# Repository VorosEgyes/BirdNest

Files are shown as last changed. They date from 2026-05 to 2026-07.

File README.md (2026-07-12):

# BirdNest ESP32-CAM Project

BirdNest is a battery-aware ESP32-CAM wildlife and bird nest monitoring project built with PlatformIO and Arduino. It captures photos on schedule or command, sends images and status updates to Telegram, and supports MQTT telemetry for smart home and IoT integrations. The firmware includes deep sleep power saving, OTA remote updates, WiFi recovery logic, DS18B20 temperature monitoring, and calibrated battery voltage reporting for reliable long-term outdoor operation.

**Single firmware binary model.** All cameras share one firmware build. Device-specific identity (label, OTA hostname, AP name) is stored in NVS at runtime, with a MAC-address-based fallback for first boot. Identity can be changed remotely via Telegram commands without reflashing.

**GitHub OTA.** Starting from v0.1.0, firmware releases are published to GitHub automatically via CI. Each device can check for and install updates over HTTPS, with SHA-256 verification and optional A/B rollback. Updates are controlled via Telegram commands at runtime.

## Hardware Design Files (KiCad)

The hardware design assets are stored in `hardware/BirdNest_pcb/`.

- Schematic: `hardware/BirdNest_pcb/BirdNest_pcb.kicad_sch`
- PCB layout: `hardware/BirdNest_pcb/BirdNest_pcb.kicad_pcb`
- KiCad project: `hardware/BirdNest_pcb/BirdNest_pcb.kicad_pro`
- KiCad project local settings: `hardware/BirdNest_pcb/BirdNest_pcb.kicad_prl`
- Backup folder: `hardware/BirdNest_pcb/BirdNest_pcb-backups/`

### 3D PCB View

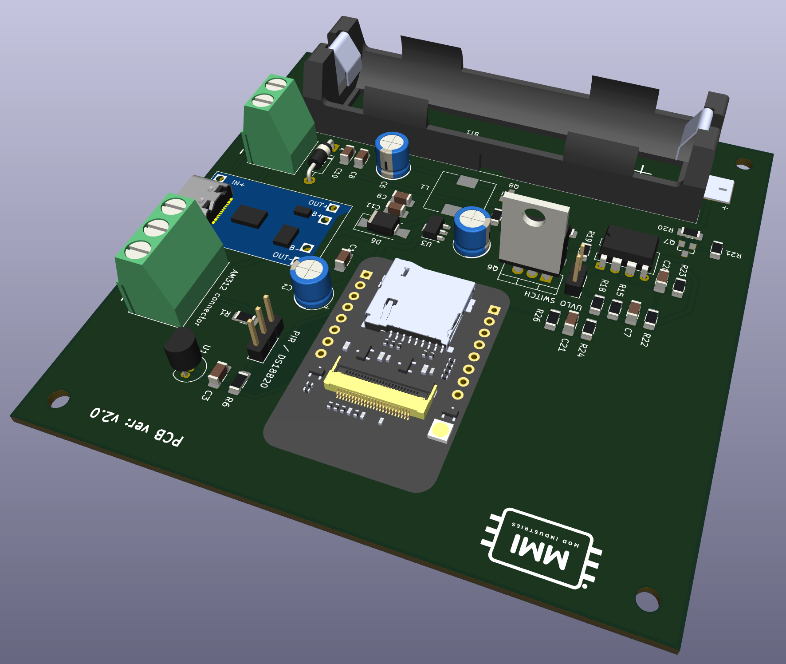
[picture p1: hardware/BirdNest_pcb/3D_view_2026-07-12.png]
BirdNest PCB 3D view


---

## Complete Hardware Pin Mapping (AI-Thinker ESP32-CAM)

| Function | Pin | Notes |
|---|---|---|
| XCLK | GPIO0 | 20 MHz camera clock |
| Camera D0 (Y2) | GPIO5 | Data pin |
| Camera D1 (Y3) | GPIO18 | Data pin |
| Camera D2 (Y4) | GPIO19 | Data pin |
| Camera D3 (Y5) | GPIO21 | Data pin |
| Camera D4 (Y6) | GPIO36 | Data pin |
| Camera D5 (Y7) | GPIO39 | Data pin |
| Camera D6 (Y8) | GPIO34 | Data pin |
| Camera D7 (Y9) | GPIO35 | Data pin |
| HREF | GPIO23 | Control line |
| VSYNC | GPIO25 | Control line |
| PCLK | GPIO22 | Control line |
| SDA (I2C) | GPIO26 | Camera I2C data |
| SCL (I2C) | GPIO27 | Camera I2C clock |
| OneWire (DS18B20) | GPIO13 | OneWire bus |
| ADC (Battery) | GPIO12 | Battery voltage measurement |
| Flash LED | GPIO4 | PWM control |

## Hardware modification

On the ESP32CAM the AMS1117 has been replaced with AP7361C-33ER-13 which consumes less. 

---

## Complete Boot Sequence (PHASE 1 in setup())

1. **Serial init** — initialize UART at 115200 baud for debug output
2. **tempInit()** — DS18B20 on GPIO13 OneWire bus with internal pull-up
3. **batteryInit()** — GPIO12 ADC setup for battery voltage reading
4. **WiFi connect phase** — STA connect with boot retries; rescue captive portal on repeated failures; deep-sleep fallback when boot connectivity cannot be recovered
5. **otaInit()** and startup OTA window — check for ArduinoOTA updates (`OTA_STARTUP_WINDOW_SEC`, or `OTA_RECOVERY_WINDOW_SEC` when recovery is armed)
5b. **ghOtaInit()** — initialize GitHub OTA module after the ArduinoOTA window settles; confirm post-install rollback health if `ESP_OTA_IMG_PENDING_VERIFY`; run auto-check and install if `otaAuto=true`
6. **syncTimeIfNeeded()** — NTP sync with up to 30 retries, 200ms between each
7. **telegramInit()** and startup message processing — initialize Telegram bot and handle first message
8. **nightSleepIfNeeded()** — if after sunset, sleep until sunrise using week-number lookup table
9. **Welcome / startup photo decision** — send welcome message only on normal boot; on timer wake, capture+send photo if maintenance mode is off
10. **Final deep sleep decision** — call `esp_deep_sleep_start()` when sleep interval is enabled and OTA is not active

---

## Photo Capture Sequence (PHASE 2)

1. **cameraInit()** — configure AI-Thinker pins (D0-D7, HREF, VSYNC, PCLK, XCLK, SCCB), JPEG mode, and grab mode
2. **PSRAM profile select** — if PSRAM is present use PSRAM frame/quality flags and `fb_count=2`, otherwise fallback profile with `fb_count=1`
3. **Init resilience** — handle `ESP_ERR_INVALID_STATE` with deinit+retry, plus second init retry after 500 ms
4. **Sensor tuning** — apply white balance, AGC/AEC settings, orientation (`/mirror` and `/flip`), and light-based OV2640 register ladder
5. **Warm-up capture phase** — capture `CAMERA_WARMUP_FRAMES` frames (current active profile: 4), with frame-grab retries (`CAMERA_FB_GET_RETRIES`)
6. **Final fallback capture** — if all warm-up grabs fail, run one final retried frame-grab attempt
7. **HTTPS multipart upload** — send Telegram `sendPhoto` request with chunked JPEG write (`8 KB` chunks) over `WiFiClientSecure`
8. **Response validation** — parse response body and treat only `"ok":true` as success; store detailed failure reason otherwise
9. **Upload retry loop** — outer retry in `captureAndSendPhoto()` with WiFi reconnect and progressive backoff (`PHOTO_SEND_RETRY_BACKOFF_MS * attempt`)
10. **cameraDeinit()** — deinitialize camera and wait 100 ms before any next init

---

## Telegram Command Processing (PHASE 3 in loop())

- 5-second polling interval
- Update ID persistence every 30 seconds
- Command table: `/status`, `/help`, `/photo`, `/sleepXX`, `/maint_on`, `/maint_off`, `/netdiag`, `/reboot`, `/reboot_ota`, `/setlabel`, `/sethostname`, `/bootstrap_prepare`, `/reset_config`, `/debug0|1|2`, `/mirror0|1`, `/flip0|1`, `/battcal`, `/battcalset`, `/battcalclear`, `/mqtt`, `/mqttset`, `/mqtttopic`, `/mqtttopic_reset`, `/mqttoff`, `/otastatus`, `/otaupdate_check`, `/otaupdate_now`, `/otaupdate_auto_on`, `/otaupdate_auto_off`, `/otachannel`, `/otatoken_set`, `/otatoken_clear`
- `/status` returns status only; full command listing is in `/help`
- Callback execution for each command

---

## Deep Sleep & Wakeup (PHASE 4)

- ESP32 hibernates: CPU off, RTC timer running
- Current draw: 100–500 µA during deep sleep
- Wakeup detection via `esp_sleep_get_wakeup_cause()`
- `fromSleep` flag behavior: sets `fromSleep` to true on wake, false on normal boot

---

## Detailed Module Descriptions

### WiFi Manager
- Telegram credential check from NVS (`botToken`, `chatId`, `debugChatId`) before connect flow
- Fail-fast STA reconnect path (`WIFI_FAIL_FAST_SEC`) when captive portal is disabled
- Rescue captive portal opens on missing Telegram fields or repeated boot failures
- Persistent WiFi failure counter (`wifiFail`) in NVS; reset to 0 on successful connect

## WiFi Connection Lifecycle (full program behavior)

### 1) Boot-time connection strategy

- The device first loads Telegram credentials and WiFi failure counter from NVS.
- If captive portal is disabled and Telegram fields are present, it tries normal STA reconnect first (`wifiInit()`).
- Boot retries are applied by the main program:
	- `WIFI_BOOT_CONNECT_RETRIES`
	- `WIFI_BOOT_RETRY_BACKOFF_SEC`
- In fail-fast mode, each WiFi attempt uses `WIFI_FAIL_FAST_SEC` timeout.

### 2) Rescue captive portal fallback

- If Telegram credentials are missing, captive portal is opened immediately.
- If `WIFI_ENABLE_CAPTIVE_PORTAL != 0`, portal path is always allowed.
- With repeated STA failures, rescue portal opens after `WIFI_RESCUE_FAIL_COUNT` failures.
- Optional periodic rescue windows use `WIFI_RESCUE_PORTAL_INTERVAL_FAILS`.
- Portal timeout uses `WIFI_RESCUE_PORTAL_TIMEOUT` (rescue) or `CONFIG_PORTAL_TIMEOUT` (normal).
- Captive portal includes custom fields for Telegram token, main chat ID, and debug chat ID.

### 3) Boot failure fallback (failsafe deep sleep)

- If WiFi cannot be established after boot retries, device enters deep sleep backoff.
- Default backoff path uses `WIFI_RETRY_BACKOFF_SEC`.
- If OTA recovery is armed, recovery sleep timing is used instead (`otaGetRecoverySleepSeconds`), including low-battery protection.

### 4) Runtime link-loss handling (while running)

- The loop continuously checks WiFi state before network-heavy tasks.
- On disconnect:
	- reconnect attempts are triggered every `WIFI_RUNTIME_RECONNECT_INTERVAL_SEC`
	- diagnostics counters are updated (`/netdiag`)
- If disconnected too long, failsafe reboot is triggered after `WIFI_RUNTIME_REBOOT_AFTER_SEC`.

### 5) OTA interaction

- OTA processing runs first in loop (`otaLoop()`).
- While OTA is active, other network work is deferred.
- Deep sleep is suppressed during active OTA transfer.
- Startup OTA polling window is dynamic: normal `OTA_STARTUP_WINDOW_SEC`, or extended `OTA_RECOVERY_WINDOW_SEC` when recovery mode is armed.
- OTA transfer watchdog restarts the device if no OTA events arrive for `OTA_STALL_TIMEOUT_SEC`.

### 6) Maintenance mode behavior

- Maintenance mode suppresses automatic sleep/photo cycle decisions, but does not bypass WiFi requirements.
- If network quality is poor, runtime reconnect/failsafe logic still applies.
- Manual diagnostics command: `/netdiag`.

### Telegram
- Bot token stored in NVS
- Poll loop every 5 seconds
- NVS persistence of sleep/maintenance settings
- `lastMsgId` tracking for message updates
- `/help` provides the full command list, while `/status` stays focused on runtime state

### Camera
- AI-Thinker pin mapping: D0–D7 data, HREF/VSYNC/PCLK control, XCLK 20 MHz
- PSRAM-aware frame profile (`CAMERA_FRAMESIZE_*`, `CAMERA_JPEG_QUALITY_*`, `fb_count`)
- Warm-up frames from build flag (`CAMERA_WARMUP_FRAMES`, active profile uses 4)
- JPEG capture and frame buffer
- Upload via HTTPS multipart POST using `WiFiClientSecure` and `writeAll()` helper
- Manual lowlight/day exposure register ladder based on ambient light register (`0x2f`)
- Multi-attempt Telegram photo upload with reconnect/backoff on failure
- Remote error diagnostics via Telegram debug messages (serial not required)

### Camera Exposure / Lowlight Logic (actual implementation)
- Ambient light value is read from sensor register `0x2f`
- `CAMERA_DAY_THRESHOLD` separates lowlight and daylight branches
- AGC is disabled (`set_gain_ctrl(0)`), gain is manual (`set_agc_gain(0)`), and exposure is controlled by register ladder writes
- A post-frame fine-tuning pass adjusts `0x47`, `0x2a`, and `0x2b` for very low to medium light
- Current implementation does not use `CAMERA_DYNAMIC_EXPOSURE_PROFILE`, `CAMERA_DAY_*`, or `CAMERA_LOWLIGHT_*` flag families

### Photo Upload Reliability and Remote Diagnostics
- Upload attempts are retried with progressive backoff and WiFi reconnect between tries.
- Retry behavior is configurable with:
	- `PHOTO_SEND_MAX_RETRIES`
	- `PHOTO_SEND_RETRY_BACKOFF_MS`
	- `CAMERA_FB_GET_RETRIES`
	- `CAMERA_FB_GET_RETRY_DELAY_MS`
- On each failed attempt, the device sends detailed failure reason to Telegram debug chat.
- Final failure message includes the last known upload error cause.

Common remote error reasons (`cameraGetLastError`):

- `empty_chat_id` - no chat ID was provided
- `missing_bot_token` - Telegram bot token is missing/empty
- `wifi_not_connected_before_upload` - WiFi dropped before upload start
- `telegram_tls_connect_failed` - TLS connection to `api.telegram.org:443` failed
- `camera_fb_get_failed_final` - frame grab failed after warm-up and final fallback attempt
- `upload_failed_headers_or_prefix` - multipart request header/prefix write failed
- `upload_chunk_write_failed_offset_N` - JPEG data upload interrupted at byte offset
- `upload_multipart_tail_failed` - multipart tail write failed
- `telegram_response_not_ok_empty_body` - Telegram returned non-OK with empty body
- `telegram_response_not_ok_...` - Telegram API responded with `ok:false` and body snippet

### Temperature
- DS18B20 on GPIO13 OneWire protocol with internal pull-up
- `TEMP_SAMPLE_COUNT` samples averaged (1–2)

### Battery
- ADC on GPIO12 with resistor divider formula
- Two-point calibration math using `bCalA`/`bCalB`
- GPIO12 is ADC2 on ESP32. While WiFi is connected, ADC2 sampling is not reliable/available, so the firmware returns the last cached valid value.
- A fresh battery sample is taken during boot before WiFi connect (`batteryRefresh()` in setup), then reused during active WiFi on ADC2 hardware.
- `/status` reports that cached value on ADC2+WiFi. This is typically the most recent wake-time sample.
- If `/status` is sent while the device is in deep sleep, it is processed after wake, so battery data in the reply reflects the new measurement from that wake cycle.

### Runtime Device Identity

All cameras run the same firmware binary. Each device's identity is stored in NVS and loaded at every boot.

| NVS key | Default | Description |
|---|---|---|
| `devLabel` | `BirdNest-XXXXXXXX` (MAC) | Human-readable device name |
| `otaHost` | `birdnest-xxxxxxxx` (MAC) | ArduinoOTA mDNS hostname |
| AP name | derived from `devLabel` + `-cfg` | Captive portal AP name (not stored separately) |

On first boot the label and hostname are generated from the lower 32 bits of the chip MAC address, so multiple devices with the same factory firmware never collide on the same LAN.

Telegram commands:
- `/setlabel <name>` — change device label (persisted in NVS, affects MQTT topics and photo captions)
- `/sethostname <name>` — change ArduinoOTA hostname (reboot required to apply mDNS)
- `/status` and welcome message show current label and OTA hostname

---

### ArduinoOTA (local network upload)
- Startup OTA window: `OTA_STARTUP_WINDOW_SEC` (default 8 s)
- Extended recovery window: `OTA_RECOVERY_WINDOW_SEC` (default 120 s) when recovery latch is armed
- OTA stall watchdog: restart if transfer is idle for `OTA_STALL_TIMEOUT_SEC`
- Recovery sleep policy: `OTA_RECOVERY_SLEEP_SEC`, with low-battery fallback `OTA_RECOVERY_LOW_BATTERY_SLEEP_SEC` below `OTA_RECOVERY_MIN_BATTERY_V`
- Recovery state is persisted in NVS via `otaArmed` and `otaCycles`
- `/reboot_ota` arms recovery and reboots — opens an extended OTA window for PlatformIO upload

---

### GitHub OTA (automatic over-the-internet updates)

Starting from v0.1.0, every `v*` git tag triggers a CI build that publishes a single firmware binary and `ota-manifest.json` to GitHub Releases. Devices can check and install these releases over HTTPS without physical access.

#### How it works

1. **Check**: device queries `api.github.com/repos/VorosEgyes/BirdNest/releases`, finds the best candidate by SemVer and channel (stable/beta), downloads `ota-manifest.json`.
2. **Install gate**: battery ≥ max(3.60 V, `manifest.min_battery_v`), WiFi stable.
3. **Install**: streams the `.bin` via HTTPS, verifies SHA-256 incrementally, writes to the inactive OTA partition, reboots.
4. **Health confirm**: on first boot after install, pings `api.github.com/rate_limit` up to 3 times; if any succeed, marks the image valid and cancels rollback.

#### Partition table requirement

GitHub OTA install requires an A/B OTA partition layout (`partitions_ota_4m.csv`). Devices previously flashed with `min_spiffs.csv` (single app partition) will run all GitHub OTA code normally but **install will be blocked** with reason `no_update_partition` until the device receives a full flash.

| Scenario | ArduinoOTA upload | GitHub OTA install |
|---|---|---|
| Device with `partitions_ota_4m.csv` | ✅ | ✅ |
| Device with `min_spiffs.csv` (old layout) | ✅ | ❌ blocked |

#### First-install / partition migration guide

To migrate an existing camera from `min_spiffs` to OTA partitions:

1. Connect via USB.
2. Run a full flash (includes partition table + bootloader + firmware):
   ```bash
   pio run -e cam1 -t upload --upload-port /dev/cu.usbserial-XXXX
   # or cam2, cam3, cam4 — all envs produce the same binary
   ```
3. After this one-time flash, all future updates can be done via GitHub OTA with no physical access.

For cameras only reachable via ArduinoOTA, use `/bootstrap_prepare` before the USB flash session to ensure maintenance mode is on and sleep is off.

#### Bootstrap preflight command

`/bootstrap_prepare` — run this before any first-install or partition migration session:
- Sets maintenance mode ON (suppresses deep sleep)
- Sets sleep interval to 0
- Disables WiFi modem sleep
- Arms ArduinoOTA recovery
- Runs and reports a preflight check:
  - Battery ≥ `BOOTSTRAP_MIN_BATTERY_V` (default 3.80 V)
  - WiFi connected and RSSI ≥ `BOOTSTRAP_MIN_RSSI_DBM` (default −82 dBm)
  - Telegram credentials present
  - OTA update partition reachable

Reports `READY` or `NOT READY` with per-check detail.

#### GitHub OTA Telegram commands

| Command | Description |
|---|---|
| `/otastatus` | JSON status: current version, channel, auto mode, pending target, last reason |
| `/otaupdate_check` | Query GitHub releases; report available version or no-update |
| `/otaupdate_now` | Check and immediately install if update found |
| `/otaupdate_auto_on` | Enable automatic check+install on every boot |
| `/otaupdate_auto_off` | Disable automatic updates (manual only) |
| `/otachannel stable\|beta` | Switch release channel |
| `/otatoken_set <token>` | Set GitHub API token (private repos; message auto-deleted) |
| `/otatoken_clear` | Clear token; drops pending private target |

#### Versioning and CI release workflow

- `FW_VERSION` is injected at build time from the nearest git tag via `scripts/fw_version_from_git.py`.
- Local/untagged builds use `0.0.0-dev` as fallback.
- CI (`release-ota.yml`) triggers on any `v*` tag push:
  - Builds `[env:release]` (same binary as camX envs)
  - Calculates SHA-256
  - Uploads `birdnest-esp32cam-vX.Y.Z.bin` and `ota-manifest.json` to GitHub Releases
- Devices on stable channel only see non-prerelease tags; beta channel sees prerelease tags too.

#### Check/backoff policy

- Auto-check runs at most once per day (`GH_OTA_DAILY_CHECK_SEC`).
- WiFi instability increments a fail streak with exponential backoff: 6 h → 12 h → 24 h → 48 h max.
- Backoff is reset after 2 consecutive stable WiFi cycles.
- Manual `/otaupdate_check` and `/otaupdate_now` bypass daily interval and backoff.

#### GitHub OTA NVS keys (namespace: `birdnest_gh`)

| Key | Type | Description |
|---|---|---|
| `otaAuto` | bool | Auto-update enabled |
| `otaChannel` | string | `stable` or `beta` |
| `otaToken` | string | GitHub API token (private repos) |
| `otaLastChk` | uint32 | Unix timestamp of last successful check |
| `otaWifiFail` | uint16 | Consecutive WiFi stability failures |
| `otaChkFail` | uint16 | Consecutive check failures |
| `otaWifiOk` | uint8 | Consecutive stable cycles (for backoff reset) |
| `otaBackoff` | uint32 | Backoff-end timestamp (0 = no backoff) |
| `otaTarget` | string | JSON-serialized pending install target |
| `otaLastReason` | string | Last OTA block/fail reason code |
| `otaRebootFlg` | bool | Set before install reboot, cleared on next boot |
| `otaLastTgt` | string | Version string of last attempted install |

### MQTT
- Runtime MQTT client with automatic reconnect
- JSON status publish to a configurable state topic (channel)
- Config stored in NVS and editable from Telegram
- Supports auth and no-auth brokers
- Periodic publish (`MQTT_STATUS_INTERVAL_SEC`) and immediate publish on boot/config change
- LWT availability support (`online` / `offline`, retained)
- Separate state/event/availability topic model
- Payload schema versioning (`schema_version`)
- GitHub OTA events published via `mqttPublishOtaEvent()` to the event topic

---

## MQTT Setup and Usage

### Default Topics

If no custom topic is set, these topics are used:

- State topic: `birdnest/<deviceLabel>/status`
- Event topic: `birdnest/<deviceLabel>/event`
- Availability topic: `birdnest/<deviceLabel>/availability`

Where `<deviceLabel>` is the runtime device identity loaded from NVS (see Runtime Device Identity section). The default is `BirdNest-XXXXXXXX` based on MAC address.

If you set a custom topic with `/mqtttopic`:

- The custom value is used as the state topic.
- If it ends with `/status`, event and availability are derived as sibling topics.
- Otherwise `/event` and `/availability` are appended.

### Telegram Commands for MQTT

- `/mqtt` - show current MQTT config and active channel
- `/mqttset <ip-or-host> <port> <user|-> <pass|->` - set broker and auth in one message
- `/mqtttopic <topic>` - set custom publish channel/topic
- `/mqtttopic_reset` - reset topic to default (`birdnest/CAMERA_LABEL/status`)
- `/mqttoff` - disable MQTT and clear broker credentials

`/mqtt` now reports:

- State topic
- Event topic
- Availability topic
- Schema version

### One-message setup examples

- Auth enabled:
	- `/mqttset 192.168.1.100 1883 mqtt_user mqtt_pass`
- No auth:
	- `/mqttset 192.168.1.100 1883 - -`

### Channel/topic examples

- Set custom channel:
	- `/mqtttopic birdnest/BirdNestCam1/status`
- Reset to default channel:
	- `/mqtttopic_reset`

### Published payloads

State payload (`status`) is JSON and includes:

- `schema_version`
- `device`
- `reason` (`boot`, `periodic`, `manual`, `config_updated`, ...)
- `ip`
- `rssi`
- `uptime_s`
- `temp_c`
- `battery_v`
- `battery_pct`
- `maint`

Event payload (`event`) is JSON and includes:

- `schema_version`
- `device`
- `event`
- `detail`
- `uptime_s`

GitHub OTA event payload additionally includes:

- `reason` — machine-readable reason code (e.g. `no_update`, `battery_low`, `sha256_mismatch`)
- `current_version` — running firmware version
- `target_version` — target version being installed (empty if check-only)
- `channel` — `stable` or `beta`

OTA event types: `ota_check_start`, `ota_check_no_update`, `ota_update_available`, `ota_install_blocked`, `ota_update_start`, `ota_update_progress`, `ota_update_ok`, `ota_update_fail`, `ota_check_fail`

Availability payload (`availability`) values:

- `online` (retained on successful connect)
- `offline` (retained via LWT or explicit MQTT disable)

---

## NVS Storage Structure

All keys live in the `birdnest` namespace unless otherwise noted.

### Device identity

| Key | Type | Description |
|---|---|---|
| `devLabel` | string | Runtime device label (default: `BirdNest-XXXXXXXX`) |
| `otaHost` | string | ArduinoOTA mDNS hostname (default: `birdnest-xxxxxxxx`) |

### Telegram credentials and runtime config

| Key | Type | Description |
|---|---|---|
| `botToken` | string | Telegram bot token |
| `chatId` | string | Telegram main chat ID |
| `debugChatId` | string | Telegram debug chat ID |
| `sleepSec` | uint32 | Deep sleep interval in seconds |
| `maintMode` | bool | Maintenance mode |
| `dbgVerb` | uint8 | Debug verbosity (0–2) |
| `camMirror` | bool | Camera mirror |
| `camFlip` | bool | Camera vertical flip |
| `lastMsgId` | int32 | Last processed Telegram update ID |

### Battery calibration

| Key | Type | Description |
|---|---|---|
| `bCalEn` | bool | Two-point calibration enabled |
| `bCalA` / `bCalB` | float | Calibration slope / offset |
| `bCalRV1/MV1/RV2/MV2` | float | Calibration reference points |

### ArduinoOTA recovery

| Key | Type | Description |
|---|---|---|
| `otaArmed` | bool | Recovery mode armed |
| `otaCycles` | uint16 | Recovery cycles remaining |

### WiFi

| Key | Type | Description |
|---|---|---|
| `wifiFail` | uint16 | Consecutive WiFi boot failure counter |

### MQTT

| Key | Type | Description |
|---|---|---|
| `mqttHost` | string | Broker host/IP |
| `mqttPort` | uint16 | Broker port |
| `mqttUser` | string | Username (optional) |
| `mqttPass` | string | Password (optional) |
| `mqttTopic` | string | Custom state topic (optional) |

### GitHub OTA (namespace: `birdnest_gh`)

| Key | Type | Description |
|---|---|---|
| `otaAuto` | bool | Auto-update enabled |
| `otaChannel` | string | `stable` or `beta` |
| `otaToken` | string | GitHub API token |
| `otaLastChk` | uint32 | Unix timestamp of last check |
| `otaWifiFail` | uint16 | WiFi stability fail streak |
| `otaChkFail` | uint16 | Check fail streak |
| `otaWifiOk` | uint8 | Stable cycles counter (backoff reset) |
| `otaBackoff` | uint32 | Backoff end timestamp |
| `otaTarget` | string | Pending install target (JSON) |
| `otaLastReason` | string | Last block/fail reason code |
| `otaRebootFlg` | bool | Set before install reboot |
| `otaLastTgt` | string | Last attempted install version |

---

## Power Consumption & Battery Life

- Awake: ~80–150 mA
- WiFi connecting: ~150 mA
- Camera: ~200 mA
- Deep sleep: ~0.1–0.5 mA

Example: 2000 mAh battery with 5-min photo interval = 100+ hours of operation
Night sleep (12 hours OFF) saves 50%+ battery

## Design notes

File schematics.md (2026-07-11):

# BirdNestCam – Schematic Documentation

---

## Table of Contents

1. [System Overview](#1-system-overview)
2. [Power Supply – Solar and Battery Path](#2-power-supply--solar-and-battery-path)
3. [UVLO – Undervoltage Lockout](#3-uvlo--undervoltage-lockout)
4. [Battery Voltage Monitor (BAT_MON)](#4-battery-voltage-monitor-batmon)
5. [Voltage Reference – TL431](#5-voltage-reference--tl431)
6. [Boost Converter – ME2188](#6-boost-converter--me2188)
7. [ESP32-CAM](#7-esp32-cam)
8. [Temperature Sensor – DS18B20](#8-temperature-sensor--ds18b20)
9. [PIR Motion Sensor](#9-pir-motion-sensor)
10. [AM312 Connector Header](#10-am312-connector-header)
11. [Review – Notes and Recommendations](#11-review--notes-and-recommendations)
12. [Bill of Materials (BOM)](#12-bill-of-materials-bom)

---

## 1. System Overview

BirdNestCam is a solar-powered bird box monitoring system using an ESP32-CAM module for image capture and delivery via Telegram. The system can draw power from two sources:

- **Solar panel** (6V nominal, ~7–8V open-circuit voltage)
- **Li-Ion battery** (3.0–4.2V)

Automatic source selection is handled by a **power path** circuit. Between captures the system enters deep sleep to minimise energy consumption.

```
Solar panel
    │
    ├─► TP4056 module (charging) ──► Li-Ion battery
    │
    └─► D1 (1N5819) ─────────────────────────────┐
                                                  ▼
TP4056 OUT+ ──► Q8 (DMG2305UX) ─────────────► SYS_PWR ──► ME2188 Boost ──► +5V ──► ESP32-CAM
                                                  ▲
Li-Ion battery ──► Q7 (DMG2305UX) ───────────────┘
        │
        └─► UVLO comparator ──► Q6 (FQP27P06) ──► SYS_BATT_SW (protection)
```

---

## 2. Power Supply – Solar and Battery Path

### 2.1 Solar Path

| Reference | Value / Type | Function |
|---|---|---|
| J3 | Solar panel connector | 6V solar input |
| U2 | TP4056_Module | Li-Ion charger module (with DW01A + FS8205 protection) |
| D1 | 1N5819 Schottky | Solar bypass diode – direct solar supply in strong sunlight |

The solar panel delivers energy via two paths:
- **Charging path:** J3 → U2 IN+ → battery charging
- **Bypass path:** J3 → D1 → SYS_PWR (direct supply, bypassing the battery)

The bypass path prevents unnecessary battery charge/discharge cycling during strong sunlight, extending battery lifetime.

> ⚠️ **Note:** The solar panel Voc (7–8V) is applied directly to SYS_PWR via the D1 bypass path. The ME2188 boost converter's maximum input voltage must be verified — if it is less than 8V, a DD4012SA buck converter should be inserted before D1, configured to output 4.2V.

### 2.2 Battery Path

| Reference | Value / Type | Function |
|---|---|---|
| BT1 | Li-Ion battery | Energy storage, 3.0–4.2V |
| Q7 | DMG2305UX (N-MOS, SOT-23) | Battery-side switch |
| R24 | 2MΩ | Gate pull-down |
| R20 | 1MΩ | Gate drive divider |
| R26 | 1MΩ | Gate drive divider |
| C21 | 100nF | Gate filter capacitor |

Q7 is an N-MOSFET that connects the battery output to the SYS_PWR rail, controlled by the UVLO logic.

### 2.3 TP4056 OUT+ Path

| Reference | Value / Type | Function |
|---|---|---|
| Q8 | DMG2305UX (N-MOS, SOT-23) | TP4056 OUT+ switch |
| R2 | 100kΩ | Gate pull-down / control |

The TP4056 module's OUT+ output connects to the SYS_PWR rail through Q8. This output is managed by the module's internal power path logic, automatically selecting solar or battery as the source.

### 2.4 SYS_BATT_SW – System Switch

| Reference | Value / Type | Function |
|---|---|---|
| Q6 | FQP27P06 (P-MOS, TO-220) | Main system power switch |
| R15 | 100kΩ | Gate pull-up |

Q6 is a P-MOSFET load switch driven by the UVLO_GATE signal. It disconnects the entire system load when the battery voltage falls to a critically low level.

---

## 3. UVLO – Undervoltage Lockout

The UVLO circuit prevents the Li-Ion battery from deep-discharging, which would cause permanent cell damage.

### Operating Principle

| Reference | Value / Type | Function |
|---|---|---|
| U7A | LM393 comparator | UVLO comparator |
| R17 | 22kΩ | REF2V5 divider, upper leg |
| R18 | 100kΩ | Hysteresis resistor |
| R22 | 39kΩ | BAT_RAW divider, upper leg |
| R23 | 100kΩ | BAT_RAW divider, lower leg |
| C20 | 100nF | Filter capacitor |
| JP7 | Jumper | Manual UVLO_GATE bypass |

**Comparator connections:**
- **Pin 3 (non-inverting, +):** REF2V5 reference (2.5V) via R17 divider
- **Pin 2 (inverting, –):** UVLO_SENSE — scaled battery voltage from R22/R23 divider
- **Pin 1 (output):** UVLO_GATE → Q6 gate

R18 implements positive feedback between the output and the non-inverting input, creating hysteresis so the switch-off and switch-on thresholds differ — preventing oscillation near the threshold.

**Estimated switching thresholds:**
- Shutdown: ~3.0–3.2V battery voltage
- Recovery: ~3.3–3.5V battery voltage (due to hysteresis)

> Exact thresholds can be calculated from the R22/R23/R17/R18 values.

---

## 4. Battery Voltage Monitor (BAT_MON)

| Reference | Value / Type | Function |
|---|---|---|
| U7B / U7C | LM393 (second comparator) | BAT_MON signal generation |
| R25 | 680Ω | BAT_RAW divider |
| C7 | 100nF | Filter capacitor |

The BAT_MON signal connects to ESP32-CAM IO13, allowing the firmware to read a digital low/high battery status. Using an LM393 comparator is preferable to the ESP32's internal ADC, which has known non-linearity issues.

---

## 5. Voltage Reference – TL431

| Reference | Value / Type | Function |
|---|---|---|
| U8 | TL431DBZ | Precision 2.5V shunt reference |
| R25 | 680Ω | Cathode resistor |

The TL431 provides a stable REF2V5 (2.5V) reference to both the UVLO and BAT_MON comparators. This is more accurate than a resistor-divided supply reference and is independent of battery state of charge.

---

## 6. Boost Converter – ME2188

| Reference | Value / Type | Function |
|---|---|---|
| U3 | ME2188 | Step-up boost converter → +5V |
| L1 | 22µH | Boost inductor |
| C6 | 100µF | Input filter (electrolytic) |
| C10 | 100nF | Input filter (ceramic) |
| C8 | 22µF | Output filter |
| C9 | 47µF | Output filter |
| C11 | 100nF | Output bypass (ceramic) |
| C12 | 100µF | Output bypass (electrolytic) |
| D6 | SS14 Schottky | Boost rectifier diode |

The ME2188 boost converter generates a stable +5V rail from SYS_PWR (3.0–4.2V from battery, or potentially higher when the solar bypass path is active).

> ⚠️ **Critical:** Verify the ME2188's absolute maximum input voltage. If the solar bypass path (D1) can deliver 7–8V to SYS_PWR and this exceeds the ME2188's rating, a DD4012SA buck converter must be inserted before D1, configured to 4.2V output.

---

## 7. ESP32-CAM

| Pin | Function | Connection |
|-----|---|---|
| 5V | Power input | +5V boost output |
| GND | Ground | GND |
| 3V3 | 3.3V output | DS18B20 VDD, internal LDO |
| IO4 | Flash LED | Do not use for external signals (bootstrap pin) |
| IO12 | General GPIO | Available |
| IO13 | BAT_MON | Battery level input |
| IO14 | General GPIO | Available |
| IO15 | General GPIO | Available |
| IO2 | General GPIO | Available |
| IO0 | Boot / GPIO | Must be pulled to GND for flash mode |

**Bypass capacitors on the ESP32-CAM power rails:**

| Reference | Value | Rail | Function |
|---|---|---|---|
| C1 | 100nF | 5V | HF noise filtering |
| C2 | 100µF | 5V | Current spike absorption |
| C3 | 100nF | 3V3 | HF noise filtering |

> C3 (100nF) is placed on the 3V3 rail. Adding a 100µF electrolytic in parallel is recommended for full transient suppression during WiFi transmissions.

---

## 8. Temperature Sensor – DS18B20

| Reference | Value / Type | Function |
|---|---|---|
| U1 | DS18B20 | 1-Wire digital temperature sensor |
| R6 | 4.7kΩ | 1-Wire pull-up resistor |

**Connections:**
- VDD → +3V3
- GND → GND
- DQ (data) → TEMP. SIG. → ESP32-CAM GPIO (via JP3 connector)

> ⚠️ Confirm which ESP32-CAM GPIO the TEMP. SIG. net connects to. IO4 is **not suitable** (flash LED and bootstrap pin conflict). Recommended: **IO12**.

---

## 9. PIR Motion Sensor

| Connector | Pin | Signal |
|---|-----|---|
| JP3 | 1 | PIR. SIG. → ESP32-CAM GPIO |
| JP3 | 2 | DS18B20 data (PIR DR) |
| JP3 | 3 | TEMP. SIG. |

The PIR sensor signal allows the ESP32-CAM to wake from deep sleep on motion detection, reducing energy consumption and increasing the proportion of interesting captures.

> ⚠️ The schematic shows both BAT_MON and PIR. SIG. assigned to IO13. These must be separated — see section 11.

---

## 10. AM312 Connector Header

| Reference | Pin | Signal |
|---|-----|---|
| J2 | 1 | +5V |
| J2 | 2 | PIR. SIG. |
| J2 | 3 | GND |

Connector for the AM312 mini PIR module. R1 (10kΩ) pull-down holds the PIR signal line stable in the idle state.

---

## 11. Review – Notes and Recommendations

### ✅ What is well designed

- **UVLO circuit** — excellent addition; protects the Li-Ion cell from deep discharge
- **TL431 reference** — accurate, supply-independent reference voltage for comparators
- **DMG2305UX switches** — compact SOT-23 N-MOSFETs, well suited for the switching role
- **Bypass capacitors** — C1/C2 on the 5V rail and C3 on the 3V3 rail are correctly placed
- **BAT_MON** — battery level is readable by firmware without using the ESP32's non-linear ADC
- **PIR sensor support** — motion-triggered wake is possible, saving significant energy
- **JP7 jumper** — UVLO can be bypassed manually during development and testing

### ⚠️ Critical Issues

#### 1. Solar bypass overvoltage on ME2188 input

The D1 (1N5819) bypass path can deliver the solar panel's open-circuit voltage (7–8V) directly to SYS_PWR and therefore to the ME2188 boost converter input.

**Fix:** Insert the **DD4012SA buck converter** before D1, configured to 4.2V output:
```
Solar → DD4012SA (→ 4.2V) → D1 → SYS_PWR
```
The DD4012SA requires a minimum input of 6.5V, so it will not conduct in weak sunlight — exactly when the bypass path should be inactive anyway. This gives natural alignment between solar availability and bypass activation.

#### 2. IO13 dual assignment

The schematic assigns both BAT_MON and PIR. SIG. to IO13. A single GPIO cannot serve two functions simultaneously.

**Fix:** Assign separate pins:
- BAT_MON → IO13
- PIR. SIG. → IO14

#### 3. DS18B20 TEMP. SIG. target pin not specified

The TEMP. SIG. net is not explicitly connected to a named ESP32-CAM GPIO in the schematic.

**Fix:** Route to **IO12** and label it clearly on the schematic.

### 🟡 Minor Recommendations

- **H1–H4 debug header** — exposes +3V3 and BAT_RAW for measurement. Add a label or note on the schematic describing its purpose.
- **Q6 FQP27P06 TO-220** — oversized for this application. If THT is required, a **BS250 (TO-92)** is a more compact P-MOSFET alternative with a lower gate threshold, better suited to 4.2V drive.
- **3V3 rail bulk capacitance** — C3 is only 100nF. A 100µF electrolytic in parallel is recommended to absorb WiFi transmission spikes on the 3V3 rail.
- **LM393 open-collector output** — the LM393 has open-collector outputs and requires a pull-up resistor to the supply on each output. Verify that pull-ups are present on the UVLO_GATE and BAT_MON nets (not clearly visible in the schematic).

---

## 12. Bill of Materials (BOM)

| Reference | Value / Type | Description |
|---|---|---|
| U1 | DS18B20 | 1-Wire temperature sensor |
| U2 | TP4056_Module | Li-Ion charger module (DW01A + FS8205) |
| U3 | ME2188 | Boost converter → +5V |
| U7A, U7B, U7C | LM393 | Dual comparator |
| U8 | TL431DBZ | 2.5V shunt voltage reference |
| U4 | ESP32-CAM | Camera + WiFi module |
| Q6 | FQP27P06 | P-MOSFET, TO-220, system load switch |
| Q7, Q8 | DMG2305UX | N-MOSFET, SOT-23, power path switches |
| D1 | 1N5819 | Schottky diode, solar bypass |
| D6 | SS14 | Schottky diode, boost rectifier |
| L1 | 22µH | Boost inductor |
| BT1 | Li-Ion | Rechargeable battery cell |
| J2 | AM312 connector | PIR sensor header |
| J3 | Solar panel connector | Solar panel input |
| JP7 | Jumper | UVLO bypass jumper |
| C1, C3, C7, C10, C11 | 100nF | Ceramic bypass capacitor |
| C2, C6, C12 | 100µF | Electrolytic filter capacitor |
| C8 | 22µF | Output filter capacitor |
| C9 | 47µF | Output filter capacitor |
| C20, C21 | 100nF | Filter capacitor |
| R1 | 10kΩ | PIR signal pull-down |
| R2 | 100kΩ | Q8 gate pull-down |
| R6 | 4.7kΩ | DS18B20 pull-up |
| R15 | 100kΩ | Q6 gate pull-up |
| R17 | 22kΩ | UVLO comparator divider |
| R18 | 100kΩ | UVLO hysteresis resistor |
| R19 | 1MΩ | Divider resistor |
| R20 | 1MΩ | Battery divider |
| R21 | 100kΩ | Battery divider |
| R22 | 39kΩ | UVLO_SENSE divider, upper leg |
| R23 | 100kΩ | UVLO_SENSE divider, lower leg |
| R24 | 2MΩ | Q7 gate pull-down |
| R25 | 680Ω | TL431 cathode resistor |
| R26 | 1MΩ | Battery divider |

---

*Documentation generated: 2026-06-07*  
*Based on: BirdNest_pcb.kicad.sch Rev v1.1*

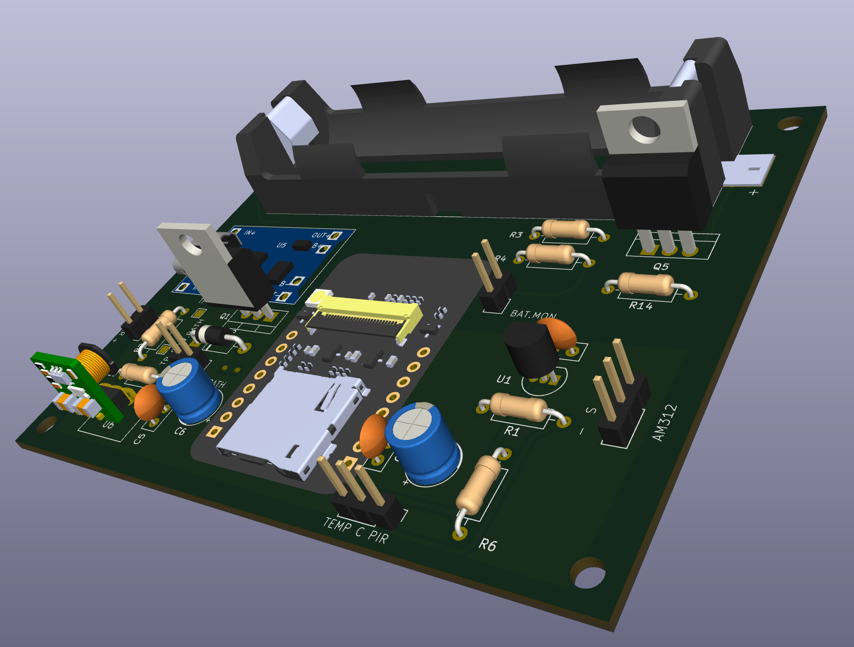
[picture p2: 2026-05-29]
hardware/BirdNest_pcb backup_260606/3D view.png

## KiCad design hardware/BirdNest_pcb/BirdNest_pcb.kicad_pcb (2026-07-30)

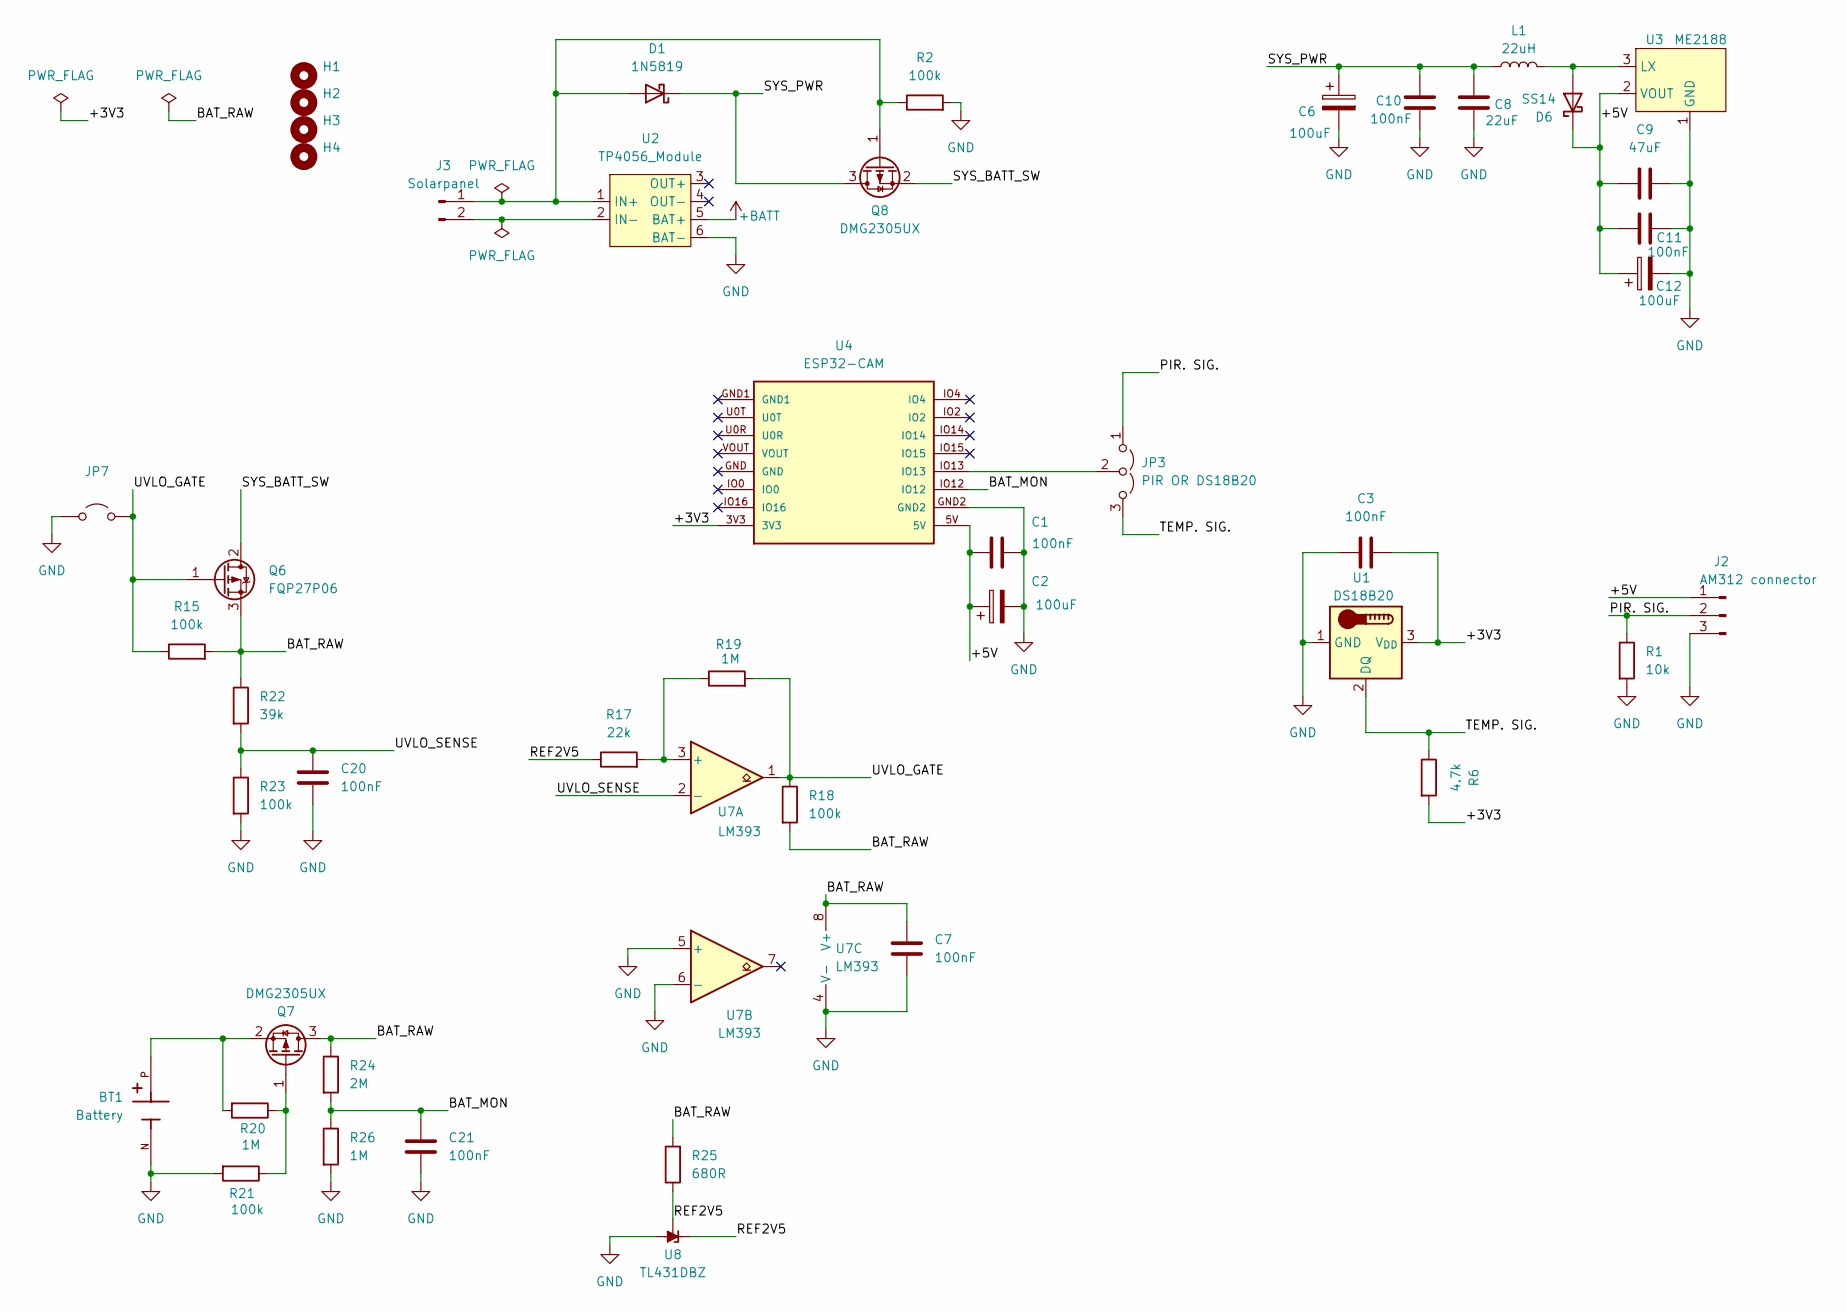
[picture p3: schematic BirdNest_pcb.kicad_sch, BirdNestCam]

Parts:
BT1: Battery; BAT_1042; PARTREV E
C1, C3, C7, C10, C11, C20, C21: 100nF; C_1206_3216Metric_Pad1.33x1.80mm_HandSolder
C2, C6, C12: 100uF; CP_Radial_D6.3mm_P2.50mm
C8: 22uF; C_1206_3216Metric_Pad1.33x1.80mm_HandSolder
C9: 47uF; C_1206_3216Metric_Pad1.33x1.80mm_HandSolder
D1: 1N5819; D_DO-41_SOD81_P10.16mm_Horizontal
D6: SS14; D_SMA-SMB_Universal_Handsoldering
H1, H2, H3, H4: MountingHole; MountingHole_3.2mm_M3
J2: AM312 connector; TerminalBlock_Phoenix_MKDS-1,5-3-5.08_1x03_P5.08mm_Horizont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
J3: Solarpanel; TerminalBlock_Phoenix_MKDS-1,5-2-5.08_1x02_P5.08mm_Horizont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
JP3: PIR OR DS18B20; PinHeader_1x03_P2.54mm_Vertical
JP7: Jumper_2_Open; PinHeader_1x02_P2.54mm_Vertical
L1: 22uH; L_10.4x10.4_H4.8
Q6: FQP27P06; TO-220-3_Vertical
Q7, Q8: DMG2305UX; SOT23
R1: 10k; R_1206_3216Metric_Pad1.30x1.75mm_HandSolder
R2, R15, R18, R21, R23: 100k; R_1206_3216Metric_Pad1.30x1.75mm_HandSolder
R6: 4.7k; R_1206_3216Metric_Pad1.30x1.75mm_HandSolder
R17: 22k; R_1206_3216Metric_Pad1.30x1.75mm_HandSolder
R19, R20, R26: 1M; R_1206_3216Metric_Pad1.30x1.75mm_HandSolder
R22: 39k; R_1206_3216Metric_Pad1.30x1.75mm_HandSolder
R24: 2M; R_1206_3216Metric_Pad1.30x1.75mm_HandSolder
R25: 680R; R_1206_3216Metric_Pad1.30x1.75mm_HandSolder
U1: DS18B20; TO-92_Inline
U2: TP4056_Module; TP4056-Module
U3: ME2188; SOT-89-3
U4: ESP32-CAM
U7: LM393; DIP-8_W7.62mm
U8: TL431DBZ; SOT-23

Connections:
+BATT: U2.5 (BAT+)
/+3V3: C3.2, R6.2, U1.3 (V_{DD}), U4.3V3
/+5V: C1.1, C2.1, C9.1, C11.2, C12.1, D6.1 (K), J2.1, U3.2 (VOUT), U4.5V
/BAT_MON: C21.1, R24.2, R26.1, U4.IO12
/BAT_RAW: C7.1, Q6.3 (S), Q7.3 (D), R15.2, R18.2, R22.1, R24.1, R25.2, U7.8 (V+)
/PIR. SIG.: J2.2, JP3.1 (A), R1.1
/REF2V5: R17.1, R25.1, U8.1 (K), U8.2 (REF)
/SYS_BATT_SW: Q6.2 (D), Q8.2 (S)
/SYS_PWR: C6.1, C8.1, C10.1, D1.1 (K), L1.1, Q8.3 (D)
/TEMP. SIG.: JP3.3 (B), R6.1, U1.2 (DQ)
/UVLO_GATE: JP7.2 (B), Q6.1 (G), R15.1, R18.1, R19.2, U7.1
/UVLO_SENSE: C20.1, R22.2, R23.1, U7.2 (-)
GND: BT1.N, C1.2, C2.2, C3.1, C6.2, C7.2, C8.2, C9.2, C10.2, C11.1, C12.2, C20.2, C21.2, J2.3, JP7.1 (A), R1.2, R2.2, R21.2, R23.2, R26.2, U1.1 (GND), U2.6 (BAT-), U3.1 (GND), U4.GND2, U7.4 (V-), U7.5 (+), U7.6 (-), U8.3 (A)
unnamed: D1.2 (A), J3.1, Q8.1 (G), R2.1, U2.1 (IN+)
unnamed: D6.2 (A), L1.2, U3.3 (LX)
unnamed: J3.2, U2.2 (IN-)
unnamed: JP3.2 (C), U4.IO13
unnamed: Q7.1 (G), R20.1, R21.1
unnamed: BT1.P, Q7.2 (S), R20.2
unnamed: R17.2, R19.1, U7.3 (+)

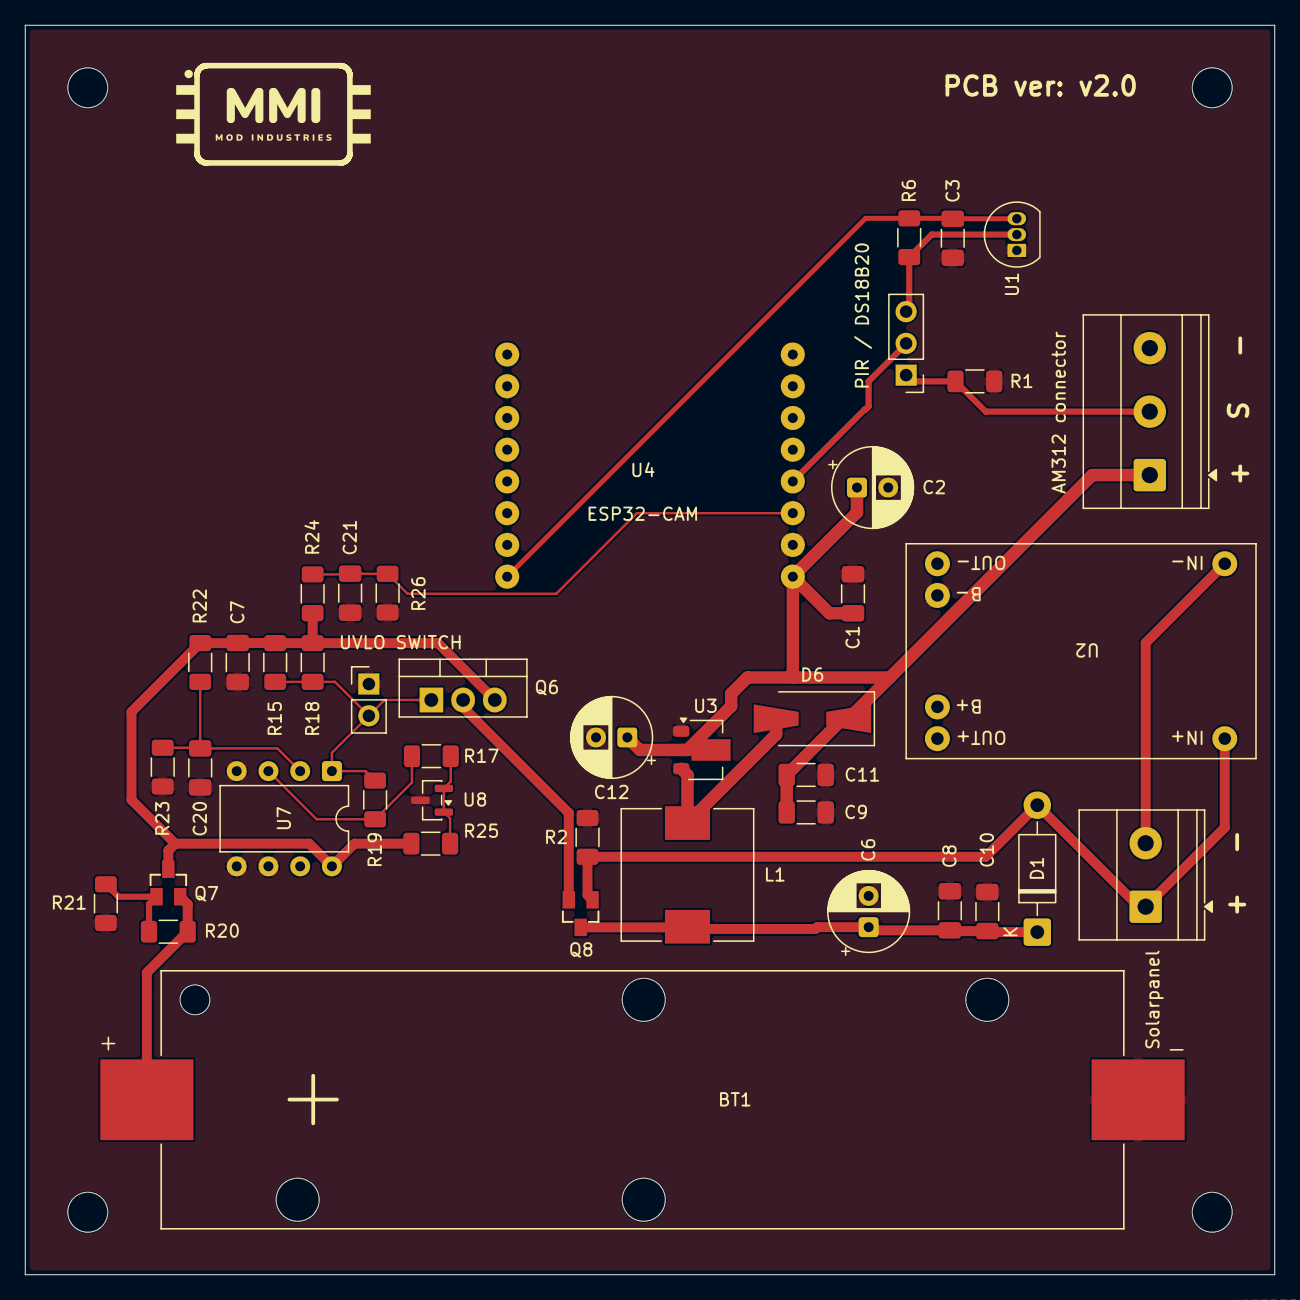
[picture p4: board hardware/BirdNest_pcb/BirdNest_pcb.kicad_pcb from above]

Board: 2 copper layers, 100.0 x 100.0 mm, 47 parts (0 on the bottom side), 19 nets.

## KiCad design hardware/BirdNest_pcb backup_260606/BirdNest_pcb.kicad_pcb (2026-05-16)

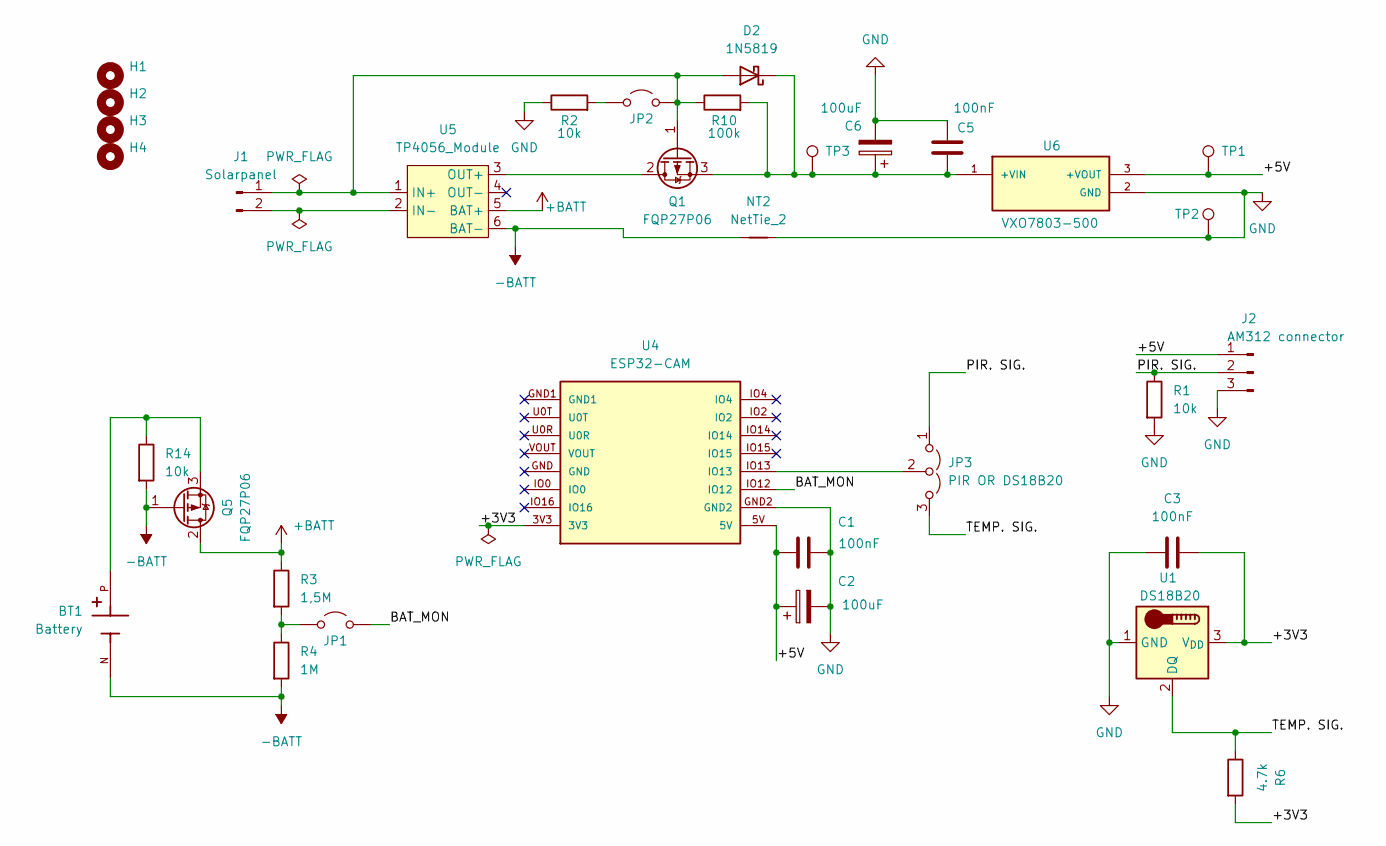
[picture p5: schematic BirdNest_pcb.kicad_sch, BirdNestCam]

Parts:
BT1: Battery; BAT_1042; PARTREV E
C1, C3, C5: 100nF; C_Disc_D5.0mm_W2.5mm_P2.50mm
C2, C6: 100uF; CP_Radial_D6.3mm_P2.50mm
D2: 1N5819; D_DO-41_SOD81_P10.16mm_Horizontal
H1, H2, H3, H4: MountingHole; MountingHole_3.2mm_M3
J1: Solarpanel; PinHeader_1x02_P2.54mm_Vertical
J2: AM312 connector; PinHeader_1x03_P2.54mm_Vertical
JP1, JP2: Jumper_2_Open; PinHeader_1x02_P2.54mm_Vertical
JP3: PIR OR DS18B20; PinHeader_1x03_P2.54mm_Vertical
NT2: NetTie_2; NetTie-2_THT_Pad1.0mm
Q1, Q5: FQP27P06; TO-220-3_Vertical
R1, R2, R14: 10k; R_Axial_DIN0207_L6.3mm_D2.5mm_P10.16mm_Horizontal
R3: 1,5M; R_Axial_DIN0207_L6.3mm_D2.5mm_P10.16mm_Horizontal
R4: 1M; R_Axial_DIN0207_L6.3mm_D2.5mm_P10.16mm_Horizontal
R6: 4.7k; R_Axial_DIN0207_L6.3mm_D2.5mm_P10.16mm_Horizontal
R10: 100k; R_Axial_DIN0207_L6.3mm_D2.5mm_P10.16mm_Horizontal
TP1, TP2, TP3: TestPoint; TestPoint_Pad_1.5x1.5mm
U1: DS18B20; TO-92_Inline
U4: ESP32-CAM
U5: TP4056_Module; TP4056-Module
U6: VXO7803-500; CONV_VXO7803-500; PARTREV 1.0

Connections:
+BATT: Q5.2 (D), R3.1, U5.5 (BAT+)
-BATT: BT1.N, NT2.1, Q5.1 (G), R4.2, R14.2, U5.6 (BAT-)
/+3V3: C3.2, R6.2, U1.3 (V_{DD}), U4.3V3
/+5V: C1.1, C2.1, J2.1, TP1.1 (1_1), U4.5V, U6.3 (+VOUT)
/BAT_MON: JP1.2 (B), U4.IO12
/PIR. SIG.: J2.2, JP3.1 (A), R1.1
/TEMP. SIG.: JP3.3 (B), R6.1, U1.2 (DQ)
GND: C1.2, C2.2, C3.1, C5.1, C6.2, J2.3, NT2.2, R1.2, R2.1, TP2.1 (1_1), U1.1 (GND), U4.GND2, U6.2 (GND)
unnamed: D2.2 (A), J1.1, JP2.2 (B), Q1.1 (G), R10.1, U5.1 (IN+)
unnamed: C5.2, C6.1, D2.1 (K), Q1.3 (S), R10.2, TP3.1 (1_1), U6.1 (+VIN)
unnamed: J1.2, U5.2 (IN-)
unnamed: JP1.1 (A), R3.2, R4.1
unnamed: JP2.1 (A), R2.2
unnamed: JP3.2 (C), U4.IO13
unnamed: Q1.2 (D), U5.3 (OUT+)
unnamed: BT1.P, Q5.3 (S), R14.1

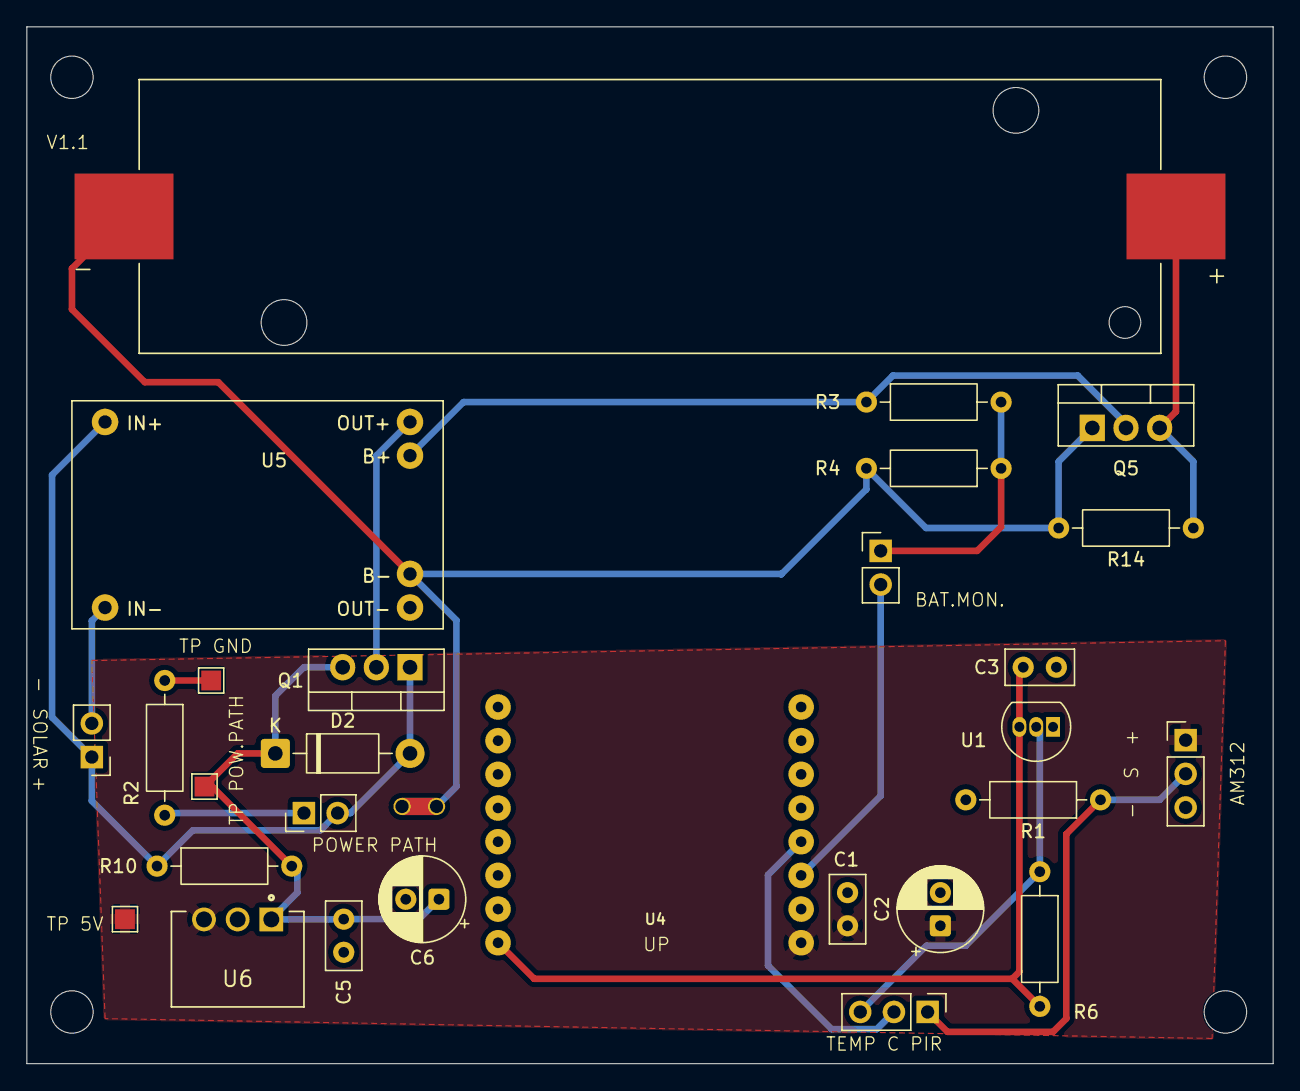
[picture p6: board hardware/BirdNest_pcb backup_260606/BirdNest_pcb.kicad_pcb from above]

Board: 2 copper layers, 94.0 x 78.2 mm, 33 parts (0 on the bottom side), 16 nets.

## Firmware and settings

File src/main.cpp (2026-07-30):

#include <Arduino.h>
#include <WiFi.h>
#include <time.h>
#include "esp_camera.h"
#include "esp_sleep.h"

#include "config.h"
#include "wifi_manager.h"
#include "telegram.h"
#include "camera.h"
#include "ota.h"
#include "gh_ota.h"
#include "temperature.h"
#include "battery.h"
#include "sun_times.h"
#include "mqtt_client.h"
#include "net_health.h"

// ============================================================
// Global timers
// ============================================================

static unsigned long s_lastPhotoMs = 0;
static const unsigned long PHOTO_INTERVAL_MS =
    static_cast<unsigned long>(PHOTO_INTERVAL_SEC) * 1000UL;
static const uint32_t WIFI_RETRY_BACKOFF_SEC = 300;
static bool s_timeSynced = false;
static unsigned long s_wifiDownSinceMs = 0;
static unsigned long s_lastWifiReconnectMs = 0;
static uint32_t s_wifiRecoveryAttempts = 0;
static unsigned long s_lastHealthReportMs = 0;
static unsigned long s_lastGoodCameraActivityMs = 0;
static unsigned long s_lastGoodWifiActivityMs = 0;

static void updateHealthActivity(bool wifiOk, bool cameraOk) {
    const unsigned long now = millis();
    if (wifiOk) s_lastGoodWifiActivityMs = now;
    if (cameraOk) s_lastGoodCameraActivityMs = now;
}

static void emitHealthReportIfNeeded() {
    const unsigned long now = millis();
    if ((now - s_lastHealthReportMs) < 600000UL) {
        return;
    }
    s_lastHealthReportMs = now;

    const bool wifiUp = (WiFi.status() == WL_CONNECTED);
    const String msg = "[HEALTH] wifi=" + String(wifiUp ? "UP" : "DOWN") +
                       " reconnects=" + String(netHealthGetReconnectAttempts()) +
                       " disconnects=" + String(netHealthGetDisconnectCount()) +
                       " camera=" + String(s_lastGoodCameraActivityMs > 0 ? "ACTIVE" : "IDLE");
    Serial.println(msg);
    telegramSendDebug(msg, 1);
}

static void prepareForSleepShutdown() {
    cameraDeinit();
    WiFi.disconnect(true, true);
    WiFi.mode(WIFI_OFF);
    yield();
}

static bool wifiConnectWithRetries() {
    const int retries = WIFI_BOOT_CONNECT_RETRIES > 0 ? WIFI_BOOT_CONNECT_RETRIES : 1;
    const unsigned long backoffMs = static_cast<unsigned long>(WIFI_BOOT_RETRY_BACKOFF_SEC) * 1000UL;

    for (int attempt = 1; attempt <= retries; ++attempt) {
        if (wifiInit()) {
            if (attempt > 1) {
                telegramSendDebug("[WIFI] connected after retry " + String(attempt), 1);
            }
            return true;
        }

        if (attempt < retries) {
            Serial.println("[WIFI] boot retry " + String(attempt) + "/" + String(retries));
            delay(backoffMs);
            yield();
        }
    }

    return false;
}

static bool wifiRuntimeRecoveryTick() {
    const unsigned long now = millis();

    if (WiFi.status() == WL_CONNECTED) {
        if (s_wifiDownSinceMs != 0) {
            netHealthOnReconnectSuccess();
        }
        s_wifiDownSinceMs = 0;
        s_wifiRecoveryAttempts = 0;
        updateHealthActivity(true, false);
        return true;
    }

    if (s_wifiDownSinceMs == 0) {
        s_wifiDownSinceMs = now;
        s_lastWifiReconnectMs = 0;
        netHealthOnWifiDown();
        Serial.println("[WIFI] runtime disconnect detected");
    }

    const unsigned long reconnectIntervalMs =
        static_cast<unsigned long>(WIFI_RUNTIME_RECONNECT_INTERVAL_SEC) * 1000UL;
    if ((now - s_lastWifiReconnectMs) >= reconnectIntervalMs) {
        s_lastWifiReconnectMs = now;
        ++s_wifiRecoveryAttempts;
        netHealthOnReconnectAttempt();
        Serial.println("[WIFI] runtime reconnect attempt " + String(s_wifiRecoveryAttempts));
        if (s_wifiRecoveryAttempts >= 4) {
            Serial.println("[WIFI] repeated reconnect failures, forcing modem reset");
            WiFi.disconnect(true, true);
            WiFi.mode(WIFI_OFF);
            delay(250);
            WiFi.mode(WIFI_STA);
            WiFi.begin();
        } else {
            WiFi.disconnect(true, true);
            WiFi.reconnect();
        }
    }

    const unsigned long rebootAfterMs =
        static_cast<unsigned long>(WIFI_RUNTIME_REBOOT_AFTER_SEC) * 1000UL;
    if (rebootAfterMs > 0 && (now - s_wifiDownSinceMs) >= rebootAfterMs && !otaIsActive()) {
        Serial.println("[WIFI] disconnected too long, rebooting failsafe");
        ESP.restart();
    }

    return false;
}

static bool syncTimeIfNeeded() {
    if (s_timeSynced) return true;

    configTzTime(NTP_TZ, NTP_SERVER_1, NTP_SERVER_2, NTP_SERVER_3);

    struct tm timeInfo;
    for (int i = 0; i < 30; ++i) {
        if (getLocalTime(&timeInfo, 500)) {
            s_timeSynced = true;
            Serial.printf("[NTP] synced: %02d:%02d:%02d\n",
                          timeInfo.tm_hour,
                          timeInfo.tm_min,
                          timeInfo.tm_sec);
            return true;
        }
        delay(200);
    }

    Serial.println("[NTP] sync failed");
    telegramSendDebug("[NTP] sync failed", 1);
    return false;
}

static String formatNextWakeTime(uint32_t seconds) {
    time_t now = time(nullptr);
    if (now <= 100000) return "unknown";

    time_t wakeAt = now + seconds;
    struct tm wakeTm;
    localtime_r(&wakeAt, &wakeTm);

    char buf[16];
    snprintf(buf, sizeof(buf), "%02d:%02d:%02d",
             wakeTm.tm_hour, wakeTm.tm_min, wakeTm.tm_sec);
    return String(buf);
}

static void enterDeepSleepSeconds(uint32_t seconds) {
    // Never enter deep sleep while an OTA transfer is in progress.
    if (otaIsActive()) {
        Serial.println("[PWR] deep sleep suppressed – OTA active");
        return;
    }
    String nextWake = syncTimeIfNeeded() ? formatNextWakeTime(seconds) : "unknown";
    String sleepMsg = "[PWR] going to deep sleep. Next wake-up: " + nextWake;

    telegramSendDebug(sleepMsg, 0);

    Serial.println("[PWR] entering deep sleep for " + String(seconds) + "s");
    prepareForSleepShutdown();
    esp_sleep_enable_timer_wakeup(static_cast<uint64_t>(seconds) * 1000000ULL);
    esp_deep_sleep_start();
}

static bool captureAndSendPhoto(const char* chatId, bool retryOnce) {
    if (!chatId || chatId[0] == '\0') return false;

    if (!cameraInit()) {
        Serial.println("[PHOTO] cameraInit FAILED");
        telegramSendDebug("[PHOTO] cameraInit failed", 0);
        return false;
    }

    const int maxTries = retryOnce ? (PHOTO_SEND_MAX_RETRIES > 1 ? PHOTO_SEND_MAX_RETRIES : 2) : 1;
    updateHealthActivity(false, true);
    bool ok = false;
    for (int attempt = 1; attempt <= maxTries; ++attempt) {
        ok = cameraSendPhoto(chatId);
        if (ok) break;

        const String failReason = cameraGetLastError();
        telegramSendDebug("[PHOTO] attempt " + String(attempt) + "/" + String(maxTries) + " failed: " + failReason, 2);

        if (attempt < maxTries) {
            Serial.println("[PHOTO] send failed, retrying...");
            cameraDeinit();
            WiFi.disconnect(true, true);
            WiFi.reconnect();
            const unsigned long backoffMs = static_cast<unsigned long>(PHOTO_SEND_RETRY_BACKOFF_MS) * static_cast<unsigned long>(attempt);
            telegramSendDebug("[PHOTO] retrying in " + String(backoffMs) + " ms (next attempt " + String(attempt + 1) + "/" + String(maxTries) + ")", 1);
            delay(backoffMs);
            yield();
        }
    }

    if (ok) {
        updateHealthActivity(true, true);
    } else {
        Serial.println("[PHOTO] forcing camera/WiFi recovery after repeated failure");
        cameraDeinit();
        WiFi.disconnect(true, true);
        WiFi.reconnect();
        updateHealthActivity(true, false);
    }

    // In maintenance mode, keep camera initialized between manual captures
    // to avoid repeated init/deinit instability on ESP32-CAM modules.
    if (!telegramIsMaintMode()) {
        cameraDeinit();
    }
    Serial.println(ok ? "[PHOTO] sent OK" : "[PHOTO] send FAILED");
    if (!ok) telegramSendDebug("[PHOTO] failed after " + String(maxTries) + " attempts. Last error: " + cameraGetLastError(), 0);
    return ok;
}

// ============================================================
// Photo callback – called by telegramLoop() on /photo command
// ============================================================

static void onPhotoRequest(const char* chatId) {
    Serial.println("[PHOTO] starting...");
    telegramSendDebug("[PHOTO] manual capture requested", 1);
    if (!captureAndSendPhoto(chatId, true)) {
        telegramSend(chatId, "Photo capture/send failed.");
    }
}

static void onSleepRequest(uint32_t sleepSec) {
    if (sleepSec > 0) {
        enterDeepSleepSeconds(sleepSec);
    }
}

// ============================================================
// Night-time sleep check
// Skips if: maintenance mode is on, NTP not synced, or daytime.
// Sleeps until sunrise (- SUNRISE_BUFFER_MIN), capped at 12 h.
// ============================================================
static void nightSleepIfNeeded() {
    if (telegramIsMaintMode()) return; // maintenance override
    if (!s_timeSynced)         return; // no NTP – can't determine night

    struct tm t;
    if (!getLocalTime(&t, 500)) return;

    // ISO week number (01-53)
    char weekBuf[4];
    strftime(weekBuf, sizeof(weekBuf), "%V", &t);
    int isoWeek    = atoi(weekBuf);
    int currentMin = t.tm_hour * 60 + t.tm_min;

    uint32_t sleepSecs = secondsUntilSunrise(isoWeek, currentMin);
    if (sleepSecs == 0) return; // daytime – proceed normally

    // Format expected wake time for the notification
    int idx = (isoWeek < 1 ? 0 : isoWeek > 52 ? 51 : isoWeek - 1);
    int wakeMin = static_cast<int>(SUN_TABLE[idx].sunrise) - static_cast<int>(SUNRISE_BUFFER_MIN) + static_cast<int>(NIGHT_WAKE_OFFSET_MIN);
    if (wakeMin < 0) wakeMin = 0;
    if (wakeMin > 1439) wakeMin = 1439;
    char wakeBuf[6];
    snprintf(wakeBuf, sizeof(wakeBuf), "%02d:%02d", wakeMin / 60, wakeMin % 60);

    uint32_t sleepHours = sleepSecs / 3600;
    uint32_t sleepMinutes = (sleepSecs % 3600) / 60;

    Serial.printf("[NIGHT] Night mode - sleeping for %uh %um until sunrise ~%s\n",
                  sleepHours, sleepMinutes, wakeBuf);

    String msg = "Night mode: sleeping for " + String(sleepHours) + "h " + String(sleepMinutes) +
                 "m, until sunrise (~" + String(wakeBuf) + ").";
    const char* chatId = getChatId();
    if (chatId && chatId[0] != '\0') telegramSend(chatId, msg);
    telegramSendDebug("[NIGHT] sleeping " + String(sleepHours) + "h " + String(sleepMinutes) +
                      "m until ~" + String(wakeBuf), 1);

    esp_sleep_enable_timer_wakeup(static_cast<uint64_t>(sleepSecs) * 1000000ULL);
    esp_deep_sleep_start();
}

// ============================================================
// setup
// ============================================================

void setup() {
    Serial.begin(115200);
    Serial.println("\n\n=== BirdNest boot ===");
    // Arduino framework: watchdog is fed by yield()/delay() in loop and long operations

    // Temperature sensor – does not depend on WiFi
    tempInit();
    batteryInit();
    batteryRefresh();
    const float batteryVoltage = batteryReadVoltage();

    // WiFi + captive portal (blocking until connected or timeout)
    Serial.println("[WIFI] connecting...");
    if (!wifiConnectWithRetries()) {
        Serial.println("[WIFI] FAILED – sleeping before retry");
        delay(500);
        uint32_t retrySleepSec = otaRecoveryIsArmed()
            ? otaGetRecoverySleepSeconds(batteryVoltage)
            : WIFI_RETRY_BACKOFF_SEC;
        enterDeepSleepSeconds(retrySleepSec);
    }
    WiFi.setSleep(false);
    netHealthOnBootConnected();
    Serial.println("[WIFI] connected: " + WiFi.localIP().toString());
    otaInit();

    // Give PlatformIO time to initiate an OTA connection before we do any
    // heavy/blocking work (Telegram HTTPS, photo capture, deep sleep).
    // Without this window, loop() may never run if sleepSec > 0.
    if (!otaStartupWindow(batteryVoltage)) {
        enterDeepSleepSeconds(otaGetRecoverySleepSeconds(batteryVoltage));
    }

    // GitHub OTA: init module, confirm post-install rollback health if needed,
    // then run auto-check/install when enabled.
    // Placed after the ArduinoOTA startup window to let the UDP/mDNS stack settle.
    ghOtaInit();
    ghOtaConfirmHealthIfPending();
    if (ghOtaIsAutoEnabled() && !telegramIsMaintMode()) {
        GhOtaTarget pendingTarget;
        if (ghOtaGetPendingTarget(pendingTarget)) {
            ghOtaInstall(pendingTarget);
        } else {
            GhOtaTarget target;
            const GhOtaCheck check = ghOtaCheckForUpdate(target, false);
            if (check == GhOtaCheck::UpdateAvailable) {
                ghOtaInstall(target);
            }
        }
    }

    syncTimeIfNeeded();

    // OTA server
   
    // Telegram bot
    Serial.println("[TG] init...");
    telegramInit();
    telegramSetPhotoCallback(onPhotoRequest);
    telegramSetSleepCallback(onSleepRequest);

    // DS18B20 diagnostics via Telegram (tempInit() already ran before WiFi)
    {
        uint8_t cnt = tempGetSensorCount();
        float   t   = tempRead();
        String diagMsg = "DS18B20 diag:\n"
                         "Sensors found: " + String(cnt) + "\n"
                         "Parasite power: " + String(tempIsParasitePower() ? "YES" : "NO") + "\n"
                         "Temp: " + (cnt > 0 ? String(t, 1) + " C" : "N/A");
        telegramSendDebug(diagMsg, 2);
    }

    // Process queued commands first (e.g. /maint_on while device was sleeping)
    // so runtime flags are up to date before any sleep decision.
    telegramProcessStartupMessages();
    mqttInit();
    mqttPublishNow("boot");

    // Night-time check: if after sunset or before sunrise, sleep until sunrise (max 12 h)
    nightSleepIfNeeded();


    // Check if we woke from deep sleep – if so, take a photo immediately
    bool fromSleep = (esp_sleep_get_wakeup_cause() == ESP_SLEEP_WAKEUP_TIMER);

     // Log current runtime config to serial and debug chat
     uint32_t sleepSec = telegramGetSleepSec();
     bool maintMode = telegramIsMaintMode();
     Serial.printf("[CFG] Deep sleep: %u sec (%u min), Maintenance: %s\n",
                   sleepSec, sleepSec / 60, maintMode ? "ON" : "OFF");
     String cfgMsg = "Config loaded from NVS:\n"
                     "Sleep: " + String(sleepSec / 60) + " min\n"
                     "Maintenance: " + String(maintMode ? "ON" : "OFF");
     telegramSendDebug(cfgMsg, 2);

     // Send welcome FIRST if not from sleep
     if (!fromSleep) {
         Serial.println("[TG] sending welcome...");
         bool ok = telegramSendWelcome();
         Serial.println(ok ? "[TG] welcome sent OK" : "[TG] welcome FAILED");
         if (!ok) telegramSendDebug("[TG] welcome message send failed", 0);
     }

    // Photo capture is only performed after timer deep-sleep wakeup
    // (and only when maintenance mode is OFF).
    if (getChatId() && getChatId()[0] != '\0') {
        if (maintMode) {
            Serial.println("[PHOTO] startup capture skipped (maintenance mode)");
            telegramSendDebug("[PHOTO] startup capture skipped (maintenance mode)", 1);
        } else {
            // Ensure no photos are sent in maintenance mode
            if (getChatId() && getChatId()[0] != '\0' && !maintMode) {
                if (fromSleep) {
                    Serial.println("[PHOTO] starting capture...");
                    telegramSendDebug("[PHOTO] wakeup capture started", 1);
                    if (!captureAndSendPhoto(getChatId(), true)) {
                        String msg = "[wakeup] Photo capture/send failed.";
                        telegramSend(getChatId(), msg);
                    } else {
                        telegramSendDebug("[PHOTO] wakeup capture sent", 1);
                    }
                }
            } else {
                Serial.println("[PHOTO] skipped due to maintenance mode");
            }
        }
    }

    if (fromSleep) {
        telegramSendDebug("[BOOT] wakeup cause: timer deep sleep", 2);
    }

    // After startup command processing (and optional wakeup photo), continue
    // the deep sleep cycle immediately.
    // This applies to both first boot and timer wakeups.
    uint32_t sleepSecNow = telegramGetSleepSec();
    if (sleepSecNow > 0 && !telegramIsMaintMode() && !otaIsActive()) {
        enterDeepSleepSeconds(sleepSecNow);
    }

    Serial.println("=== setup done ===");
}

// ============================================================
// loop
// ============================================================

void loop() {
    yield();
    // OTA updates – always first
    otaLoop();

    // While OTA is active, do not run any other blocking network work.
    if (otaIsActive()) {
        delay(2);
        return;
    }

    // Keep the node reachable on unstable links.
    if (!wifiRuntimeRecoveryTick()) {
        emitHealthReportIfNeeded();
        delay(20);
        return;
    }

    emitHealthReportIfNeeded();

    // Handle incoming Telegram commands
    telegramLoop();
    mqttLoop();

    // Periodic photo + deep sleep cycle
    unsigned long now = millis();
    if (now - s_lastPhotoMs >= PHOTO_INTERVAL_MS) {
        s_lastPhotoMs = now;

        // Enter deep sleep if configured and maintenance mode is off.
        // On wakeup, setup() will take the photo automatically.
        uint32_t sleepSec = telegramGetSleepSec();
        if (sleepSec > 0 && !telegramIsMaintMode()) {
            enterDeepSleepSeconds(sleepSec);
        }

        // Deep sleep disabled – take photo inline only when maintenance mode is OFF
        if (getChatId() && getChatId()[0] != '\0' && !telegramIsMaintMode()) {
            captureAndSendPhoto(getChatId(), true);
        }
    }

    // Short delay to feed watchdog
    delay(10);
}

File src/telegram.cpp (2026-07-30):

#include "telegram.h"
#include "wifi_manager.h"
#include "config.h"
#include "temperature.h"
#include "battery.h"
#include "ota.h"
#include "gh_ota.h"
#include "mqtt_client.h"
#include "net_health.h"

#include <WiFi.h>
#include <WiFiClientSecure.h>
#include <UniversalTelegramBot.h>
#include <Arduino.h>
#include <Preferences.h>
#include <esp_ota_ops.h>

// static objects, not pointers, token set at construct time.
static WiFiClientSecure s_client;
static String           s_token;
static UniversalTelegramBot* s_bot = nullptr;

static const unsigned long BOT_POLL_INTERVAL_MS  = 10000UL; // 10s – saves radio vs 1s/5s polling

static unsigned long s_lastBotCheck  = 0;
static bool          s_maintMode     = false;
static uint32_t      s_sleepSec      = DEEP_SLEEP_SEC;
static uint8_t       s_debugVerbosity = 1; // 0=minimal, 1=normal, 2=verbose
static bool          s_camMirror     = true;
static bool          s_camFlip       = false;
static int32_t       s_lastMessageId = 0;  // Last processed Telegram update_id
static bool          s_lastMsgDirty  = false;
static unsigned long s_lastMsgPersistMs = 0;
typedef void (*PhotoCallback)(const char*);
static PhotoCallback s_photoCb       = nullptr;
static SleepCallback s_sleepCb       = nullptr;

static const uint16_t STARTUP_MSG_PROCESS_LIMIT = 10;
static const unsigned long STARTUP_MSG_TIME_LIMIT_MS = 5000UL;
static const unsigned long LAST_MSG_PERSIST_INTERVAL_MS = 30000UL;

static void persistLastMessageId(bool force = false) {
    if (!s_lastMsgDirty) return;

    unsigned long now = millis();
    if (!force && (now - s_lastMsgPersistMs) < LAST_MSG_PERSIST_INTERVAL_MS) {
        return;
    }

    Preferences prefs;
    prefs.begin(NVS_NAMESPACE, /*readOnly=*/false);
    prefs.putLong("lastMsgId", s_lastMessageId);
    prefs.end();

    s_lastMsgDirty = false;
    s_lastMsgPersistMs = now;
}

static void loadRuntimeConfig() {
    Preferences prefs;
    prefs.begin(NVS_NAMESPACE, /*readOnly=*/true);
    s_sleepSec = prefs.getUInt("sleepSec", DEEP_SLEEP_SEC);
    s_maintMode = prefs.getBool("maintMode", false);
    s_debugVerbosity = prefs.getUChar("dbgVerb", 1);
    s_camMirror = prefs.getBool("camMirror", true);
    s_camFlip = prefs.getBool("camFlip", false);
    s_lastMessageId = prefs.getLong("lastMsgId", 0);
    if (s_debugVerbosity > 2) s_debugVerbosity = 2;
    prefs.end();
}

static void saveRuntimeConfig() {
    Preferences prefs;
    prefs.begin(NVS_NAMESPACE, /*readOnly=*/false);
    prefs.putUInt("sleepSec", s_sleepSec);
    prefs.putBool("maintMode", s_maintMode);
    prefs.putUChar("dbgVerb", s_debugVerbosity);
    prefs.putBool("camMirror", s_camMirror);
    prefs.putBool("camFlip", s_camFlip);
    prefs.putLong("lastMsgId", s_lastMessageId);
    prefs.end();
    s_lastMsgDirty = false;
    s_lastMsgPersistMs = millis();
}

// ============================================================
// Chat ID helper
// ============================================================

static bool chatIdMatches(const String& incoming, const char* stored) {
    if (!stored || stored[0] == '\0') return false;
    String s = String(stored);
    s.trim();
    return incoming == s;
}

static String normalizeCommand(String text) {
    int atIdx = text.indexOf('@');
    if (atIdx > 0) text = text.substring(0, atIdx);
    text.trim();
    return text;
}

static bool parseBatteryCalibrationArgs(const String& text, float& realV1, float& measuredV1, float& realV2, float& measuredV2) {
    const int firstSpace = text.indexOf(' ');
    if (firstSpace < 0) return false;

    String args = text.substring(firstSpace + 1);
    args.trim();

    float parsed[4] = {0.0f, 0.0f, 0.0f, 0.0f};
    int count = 0;
    int start = 0;

    while (start < args.length() && count < 4) {
        while (start < args.length() && args.charAt(start) == ' ') ++start;
        if (start >= args.length()) break;

        int end = args.indexOf(' ', start);
        if (end < 0) end = args.length();

        String token = args.substring(start, end);
        token.trim();
        token.replace(',', '.');
        if (token.length() == 0) return false;

        parsed[count++] = token.toFloat();
        start = end + 1;
    }

    if (count != 4) return false;

    realV1 = parsed[0];
    measuredV1 = parsed[1];
    realV2 = parsed[2];
    measuredV2 = parsed[3];
    return true;
}

static bool parseMqttSetArgs(const String& text, String& host, uint16_t& port, String& user, String& pass) {
    const int firstSpace = text.indexOf(' ');
    if (firstSpace < 0) return false;

    String args = text.substring(firstSpace + 1);
    args.trim();

    String parts[4];
    int count = 0;
    int start = 0;

    while (start < args.length() && count < 4) {
        while (start < args.length() && args.charAt(start) == ' ') ++start;
        if (start >= args.length()) break;

        int end = args.indexOf(' ', start);
        if (end < 0) end = args.length();

        parts[count++] = args.substring(start, end);
        start = end + 1;
    }

    if (count != 4) return false;

    host = parts[0];
    host.trim();
    if (host.length() == 0) return false;

    String portStr = parts[1];
    portStr.trim();
    for (size_t i = 0; i < portStr.length(); ++i) {
        if (!isdigit(static_cast<unsigned char>(portStr.charAt(i)))) return false;
    }
    unsigned long parsedPort = portStr.toInt();
    if (parsedPort == 0 || parsedPort > 65535UL) return false;
    port = static_cast<uint16_t>(parsedPort);

    user = parts[2];
    pass = parts[3];
    user.trim();
    pass.trim();

    if (user == "-") user = "";
    if (pass == "-") pass = "";

    return true;
}

static const char* wifiRssiQuality(long rssiDbm) {
    if (rssiDbm >= -55) return "excellent";
    if (rssiDbm >= -67) return "good";
    if (rssiDbm >= -75) return "fair";
    if (rssiDbm >= -85) return "weak";
    return "very weak";
}
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

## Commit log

2026-04-30 initial commit – 2026-04-30
2026-05-12 Add configurable battery monitor and improve OTA robustness
2026-05-16 Add battery two-point calibration with Telegram commands and fix reboot behavior
    - Implement persistent per-camera battery calibration via NVS with two-point linear model
    - Add Telegram commands: /battcal, /battcalset, /battcalclear (with /batcal* aliases)
    - Update measured divider resistor values (1.95M / 1.024M)
    - Change /reboot to plain restart (remove OTA recovery arming)
    - Remove /ota_cancel command
    - Display raw and calibrated battery voltage in status messages
    [battery.cpp, telegram.cpp]
2026-05-16 Add KiCad hardware project (schematic and PCB layout)
    - Integrate BirdNest PCB design into repository
    - Include KiCad schematic (BirdNest_pcb.kicad_sch)
    - Include PCB layout (BirdNest_pcb.kicad_pcb)
    - Include project file (BirdNest_pcb.kicad_pro)
    - Update .gitignore to exclude KiCad temp files, backups, and lock files
    [BirdNest_pcb.kicad_pcb, BirdNest_pcb.kicad_sch]
2026-05-16 Update BirdNest firmware and PCB design
    [BirdNest_pcb.kicad_pcb, BirdNest_pcb.kicad_sch]
2026-05-16 Fix GPIO pin assignments in README: battery ADC GPIO12, correct camera pin mapping
2026-05-29 Update docs with battery and hardware details
2026-06-06 Include camera label in Telegram debug messages
2026-06-06 Update camera runtime behavior
2026-06-06 Update main application flow
2026-06-19 Add detailed Copilot instructions grounded in actual implementation
2026-07-11 feat: single-binary multi-device model + GitHub OTA (v0.1.0)
    - Runtime device identity (label/hostname) via NVS, MAC-based fallback
    - OTA-compatible partition table (A/B, 2x1.9MB) replacing min_spiffs
    - FW versioning via git tag (scripts/fw_version_from_git.py)
    - GitHub OTA module: check/install/rollback with SHA-256 verification
    - MQTT OTA event telemetry (mqttPublishOtaEvent)
    - New Telegram commands: /otastatus /otaupdate_check /otaupdate_now
    /otaupdate_auto_on|off /otachannel /otatoken_set /otatoken_clear
    /setlabel /sethostname /bootstrap_prepare /reboot_ota
    - CI release workflow: 1 bin + 1 manifest per git tag
    - Bootstrap preflight for safe first remote install
    [BirdNest_pcb.kicad_pcb, BirdNest_pcb.kicad_sch, partitions_ota_4m.csv]
2026-07-12 hw: update BirdNest PCB design files
    [BirdNest_pcb.kicad_pcb, BirdNest_pcb.kicad_sch]
2026-07-12 docs(hw): refresh 3D PCB view image link
2026-07-30 Improve Wi-Fi and camera recovery robustness
2026-07-30 Relax OTA Wi-Fi strength gate for weak-signal cameras
2026-07-30 Include hardware updates and generated Gerber output
    [BirdNest_pcb-B_Cu.gbl, BirdNest_pcb-B_Mask.gbs, BirdNest_pcb-B_Paste.gbp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]
2026-07-31 OTA v0.1.3: H-2 token-failure deleteMessage + H-4 /reset_config OTA NVS törlés
    H-2: /otatoken_set failure path most már deleteMessage-et hív a rossz
    hosszúságú token chat history-ból való törlésére, és a 'Token rejected:
    must be 10..200 chars (got N)' üzenetben megmondja a konkrét hosszt,
    hogy az operátor tudja mi a gond (korábban csak 'Token save failed.').
    H-4: Új ghOtaResetAll() API a gh_ota modulban, ami a teljes
    GH_OTA_NVS_NAMESPACE (birdnest_gh) tartalmát törli. A /reset_config
    handler ezt hívja a wifiReset() előtt, így a GitHub token (plaintext)
    nem éli túl a factory resetet — kritikus, ha az eszközt eladják vagy
    újrahasznosítják.
    Lásd: /opt/data/Sha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
    [telegram.cpp]
2026-07-31 OTA v0.1.3: M-9 0.0.0-dev fallback --allow-local-build flag
    A fw_version_from_git.py fallback verziója (0.0.0-dev) a SemVer
    precedence miatt bármely ≥ 1.0.0 release-re 'update available'-t
    jelent — meglepetésszerű update-et okozhat, ha egy operátor helyi
    build-et flashel és elfelejti a tag-et.
    Most a /otastatus JSON-ban 'local_build' bool mező jelzi, ha a
    FW_VERSION == '0.0.0-dev', és a /otaupdate_check [--allow-local-build],
    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
2026-07-31 Send startup photo after normal boot
    Capture and send one startup photo on cold boot outside maintenance mode so operators can verify the camera and Telegram path.
2026-07-31 Refresh OTA and hardware documentation
    Clarify OTA install gating and partition requirements, and update hardware notes to match the current schematic.
2026-07-31 OTA v0.1.3: M-11 esp_ota_abort esp_ota_end failed path
    A ghOtaInstall esp_ota_end failed ága most meghívja az esp_ota_abort(otaHandle)-et
    is a savePendingTarget előtt. Az ESP-IDF docs szerint az esp_ota_end failed
    esetén a handle-t abortálni kell, hogy a flash write-protected állapot
    felszabaduljon — egyébként a következő esp_ota_begin ugyanazon a partíción
    ESP_ERR_INVALID_STATE-tel bukhat.
    Megjegyzés: a swarm review a 734/742. sorokat jelölte meg first-ben (az
    abortInstall lambda hívásainál), de ezek a lambda-n belül már hívják az
    esp_ota_abort-ot. A tényleges bug a 812-816. sorban volt, ahol az
    esp_ota_end failed path kihagyta az abort-ot. A swarm review-t (v2 revi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
2026-07-31 OTA v0.1.3: M-10 battery 0-bypass fail-safe gate
    A ghOtaInstall battery gate átalakítása: a korábbi 'if (battery > 0.0f
    && battery < threshold)' feltétel kettévált. Ha a battery-readings <= 0.0f
    (törött ADC, levált feszültségosztó, miskalibrált szenzor), az install
    hard fail-t kap OTA_REASON_BATTERY_UNKNOWN indokkal — a korábbi viselkedés
    engedélyezte volna a telepítést, ami a flash ~30 s-os periódusa alatt a
    partíció corruptiójához (brick) vezethet, ha az akku a telepítés közben
    hal meg.
    Új konstans: OTA_REASON_BATTERY_UNKNOWN = 'battery_unknown'.
    Lásd: /opt/data/Shared/outbox/reports/Alfred_review_OTA_Design_v2_swarm.md
    Swarm review: M-10 (Prof B10).
2026-07-31 OTA v0.1.3: M-2 SemVer parser refaktor (S1-S7)
    A parseSemVer, comparePrereleaseToken, comparePrerelease, semVerCompare
    függvények refaktorja a SemVer 2.0.0 spec szigorú betartására.
    S1: build metadata ('+...') kivágása a prerelease előtt, out.build-be kerül.
    S2: numeric identifier check ([0-9]+, no leading zeros) a major/minor/patch
    és minden prerelease tokenre; atoi → toInt() csak validált stringre.
    S3: comparePrereleaseToken strict numeric/alphanumeric detektálás —
    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
2026-07-31 OTA v0.1.3 doc: OTA_Design.md átmásolása + C-4 manifest-MITM pontosítás
    A docs/OTA_Design.md átmásolása a /opt/data/Shared/inbox/from-mac/OTA_Design.md
    forrásból (841 sor, Miklós Mac-jéről). A from-mac forrás érintetlen marad.
    C-4: A §12.0 'The sha256 manifest check (8.1.1) is the integrity guarantee
    for the binary, not the TLS chain' állítás félrevezető volt. A patched
    változat egyértelműsíti: SHA256 csak a 'binary integrity given a trusted
    manifest'-et védi, a manifest integritása a TLS láncon múlik. Az on-path
    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
2026-07-31 OTA v0.1.3 doc: H-1 §10.2.1 reason codes operator view
    A /otaupdate_check és /otaupdate_now 'skipped/failed' válaszai eddig
    'See debug chat' formájúak voltak, ami a 24 reason code-ból egyet sem
    magyarázott el. A §10.2.1 új alfejezet egy 25-soros táblázatban
    (reason code / likely cause / operator action) minden kódhoz ad
    ember-olvasható leírást és konkrét cselekvési javaslatot.
    Az új battery_unknown reason (M-10 kód-patch-ből) is bekerül a táblázatba.
    Swarm review: H-1 (Martin H2).
    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
2026-07-31 OTA v0.1.3 doc: H-3 docs/RELEASE.md fleet rollout procedure
    A 4-kamerás fleet távoli menedzseléséhez release playbook. Tartalom:
    1. Pre-release checklist (8 v0.1.3 patch, build clean, sdkconfig,
    FW_VERSION, release notes draft).
    2. Tag & release sequence (kézi jóváhagyás, Alfred-féle workflow push,
    v*-prefix asset naming).
    3. Fleet rollout procedure 3 fázisban:
    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
2026-07-31 OTA v0.1.3 doc: H-5 auto-update default OFF figyelmeztetés
    A §10.1-ben az /otaupdate_auto_on parancshoz '(default OFF — see 10.2.2;
    the operator must explicitly enable auto-update)' annotáció került, és
    egy Note block a §10.1 aljára, ami explicit kimondja, hogy a release
    cut NEM indít auto-rolloutot.
    Az új §10.2.2 alpont dokumentálja a default-OFF policy-t:
    - Boot/factory reset/OTA update után az otaAuto flag false.
    - Csak /otaupdate_auto_on állítja true-ba.
    - A /status JSON output elején a 'local_build' boolean és 'auto' mező
    látható.
    - A /help a végén ezt a figyelmeztetést mutatja.
    A swarm review H-5 (Martin H4) findingját zárja.
    Lásd: /opt/data/Shared/outb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
2026-07-31 OTA v0.1.3 doc: M-1/M-3/M-7/M-8 string-és details cleanup
    M-1: §6.2 RSSI threshold doc reconciled. A 246. sor most jelzi, hogy a
    RSSI threshold defined but not currently enforced — a kód-oldali RSSI
    check dead code (fleet review 59c7122 commit eltávolította), a gate
    kizárólag a ghOtaHealthProbe() HTTPS reachability-n múlik.
    M-3: §5.1.1 FW_VERSION formátum egységesítve. A build flag 'v' prefix
    opcionális, a parseSemVer (S6 fix) mindkettőt elfogadja.
    M-7: User-Agent: RaisedGarden-OTA -> BirdNest-OTA.
    M-8: Asset nevek raisedgarden-esp32c3 -> birdnest-esp32cam, v0.1.3 /
    v0.1.4-beta.1 formátumra.
    További cleanup: doc title, intro, OTA_GH_REPO, Phase 3 checklist, pio
    build pa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
2026-07-31 OTA v0.1.3 doc: M-4 NVS / M-5 API surface / M-6 MQTT payload
    M-4: §9 NVS tábla kiegészítése 3 kulccsal (otaWifiOk, otaRebootFlg,
    otaLastTgt) és a §9.1 default tábla 3 új default sorral. Továbbá a
    namespace raised_garden -> birdnest_gh a §9-ben és a §20.1-ben.
    M-5: §14 API surface frissítése. A ghOtaCheckForUpdate és ghOtaInstall
    szignatúra kiegészítve a 'bool manualOverride = false' paraméterrel,
    dokumentálva, hogy a manual override bypassolja a time/backoff és
    Wi-Fi stability gate-eket, de a battery threshold és private-token
    rule-okat továbbra is betartja.
    M-6: §11 MQTT payload séma frissítése. A 4 mezős lista a teljes 8
    mezős kód-oldali sémára (schema_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
2026-07-31 OTA v0.1.3: release notes draft (HU/EN)
    A v0.1.3 release gate release notes-ének draftja. Tartalom:
    - What's new: anti-bricking (sdkconfig, boot order, battery 0-bypass),
    OTA control surface (token failure deleteMessage, /reset_config OTA
    NVS, --allow-local-build flag), SemVer parser refaktor (S1-S7),
    új battery_unknown reason + §10.2.1 operator-view table.
    - Documentation: docs/OTA_Design.md BirdNest-native, docs/RELEASE.md
    fleet rollout playbook, auto-update default OFF reminder.
    - Known limitations: /otarollback (1.4.0), no CA-bundle, RSSI dead
    code, L-1..L-12 cleanup (v0.1.4).
    - Upgrade notes: NVS namespace preserved, asset URL, auto-update OFF,
    /otastatus spot-check.
    - Fl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
2026-07-31 Fix WiFi persistence and boot MQTT connect
    Preserve saved WiFi credentials across deep sleep and recovery paths. Allow MQTT to attempt its initial broker connection immediately after boot.
    [main.cpp]
2026-07-31 Fix GitHub OTA release checks
    Defer OTA commands outside Telegram parsing, move release JSON buffers to PSRAM, and use bounded native HTTPS requests with verified GitHub CA trust. Retain reset-stage diagnostics and align cam1 OTA targeting.
    [main.cpp, telegram.cpp]
2026-07-31 Fix deep sleep blocked by OTA auto-check
    [main.cpp, telegram.cpp]
2026-09-06 Fix OTA manifest fetch failing on cross-CDN redirect (302)
    browser_download_url/asset URLs redirect github.com -> objects.githubusercontent.com,
    which uses a different CA chain than the pinned GitHub cert. Skip cert pinning for
    the manifest fetch (matches the already-insecure binary download path) so the
    redirect's TLS handshake succeeds.
